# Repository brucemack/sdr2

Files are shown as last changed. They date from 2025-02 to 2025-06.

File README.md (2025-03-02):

Overview
========

This is a homebrew SDR rig with no dependency on external computers/soundcards/etc. 

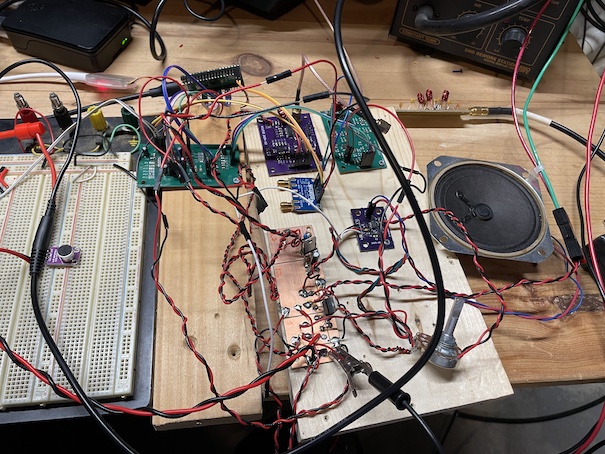
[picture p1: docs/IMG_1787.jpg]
System Picture


Build/Debug Commands
====================

One-time setup of make process:

        git submodule update --init
        mkdir build
        cd build
        cmake -DPICO_BOARD=pico2 ..

Command used to flash code to board:        

        ~/git/openocd/src/openocd -s ~/git/openocd/tcl -f interface/cmsis-dap.cfg -f target/rp2350.cfg -c "adapter speed 5000" -c "rp2350.dap.core1 cortex_m reset_config sysresetreq" -c "program main.elf verify reset exit"

Pico 2 Pinout Notes
===================
```
GP0  - (Reserved for UART0 TX)
GP1  - (Reserved for UART0 RX)

GP2  - 
GP3  - 
GP4  - I2S SCK out to PCM1804 ADC and PCM5100 DAC
GP5  - RST out to PCM1804 ADC

GP6  - I2S DIN in from PC1804 ADC
GP7  - I2S BCK out to PC1804 ADC
GP8  - I2S LRCK out to PC1804 ADC
GP9  - I2S DOUT out to PCM5100 DAC

GP10 - I2S BCK out to PCM5100 DAC
GP11 - I2S LRCK out to PCM5100 DAC
GP12 - User button input 0
GP13 - User button input 1
GP14 - PTT input 
GP15 - 
GP16 - I2C0 SDA for Si5351 (Addr 0x60)
GP17 - I2C0 SCL for Si5351 (Addr 0x60)

GP18 - I2C1 SDA for display and IO expander
GP19 - I2C1 SCL for display and IO expander
GP20 - Rotary encoder I channel input
GP21 - Rotary encoder Q channel input

GP22 - 
GP26 - ADC0 for forward power
GP27 - ADC1 for reverse power
GP28 - 
```
IO Expander Notes
=================
```
P0 - User indicator LED output
P1 - Audio amplifier enable (Low=enable output, high=shutdown amplifier)
P2 - ADC Input Select (Low=Microphone preamp out, High=QSD channel out)
P3 - TX band select 0
P4 - TX band select 1
P5 - RX band select 0
P6 - RX band select 1
P7 - Transmit PA enable (active low)
```

Wiring Notes
============

* TXRX board I_PLUS (J4:1) -> Audio Breakout INL_PLUS (J4:1)
* TXRX board I_MINUS (J4:2) -> Audio Breakout INL_MINUS (J4:2)
* TXRX board Q_PLUS (J4:3) -> Audio Breakout INR_PLUS (J4:4)
* TXRX board Q_MINUS (J4:5) -> Audio Breakout INR_MINUS (J4:3)
* Microphone input is connected to the INL_PLUS/INL_MINUS pins on the audio breakout board.

Hardware Notes
==============

### Instrumentation Amplifiers on Receive Board

See Horowitz and Hill (3rd ed, section 5.16, figure 5.88) for a description of the 
instrumentation amplifier configuration used on the receive board.  Gain for this amplifier is 
controlled determined by 1 + 2 R<sub>f</sub> / R<sub>g</sub>.  Notice that the feedback 
path is tapped after a 47 ohm resistor to set the output impedance of the stage.

Assuming R<sub>f</sub> is 520, R<sub>g</sub> is 100, the theoretical gain is about 11.

### Random

dBm = 30 + 20 * log(Vrms/sqrt(Z0))

Research
========

Consider the PCM1863 ADC? 

Consider the TS5A4624 analog switch (logic high = 2.4V w/ 5V supply)

Consider PCF8574A IO expander: https://www.ti.com/lit/ds/symlink/pcf8574a.pdf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

RF Transistor: https://www.nxp.com/docs/en/data-sheet/BFU590G.pdf

References
==========

[PCM1804 Datasheet](https://www.ti.com/lit/ds/symlink/pcm1804.pdf)
[PCM5100 Datasheet](https://www.ti.com/lit/ds/symlink/pcm5102.pdf)

Steps to Build CMSIS-DSP
========================

The library gets built once in a parallel project:

        cd ~/pico
        mkdir CMSISDSP
        cd CMSISDSP
        git clone https://github.com/ARM-software/CMSIS-DSP.git        
        git clone https://github.com/ARM-software/CMSIS_6.git
        cp $PICO_SDK_PATH/external/pico_sdk_import.cmake .

Then setup the CMakeLists.txt shown below and build:

        mkdir build
        cd build
        # IMPORTANT! pico2 build enables the generation of FPU instructions
        cmake -DPICO_BOARD=pico2 ..
        make -j4

What the CMakeLists.txt looks like:

```
cmake_minimum_required (VERSION 3.6)

# Pull in Pico SDK (must be before project)
include(pico_sdk_import.cmake) 

set(HOME $ENV{HOME})
set(CMSISDSP ${HOME}/pico/CMSISDSP/CMSIS-DSP)
set(CMSISCORE ${HOME}/pico/CMSISDSP/CMSIS_6/CMSIS/Core)

# Define the project
project (cmsis-dsp VERSION 0.1)

# Initialise the Pico SDK
pico_sdk_init()

add_subdirectory(${CMSISDSP}/Source bin_dsp)

target_compile_options(CMSISDSP PUBLIC 
    -Wsign-compare
    -Wdouble-promotion
    -Ofast -ffast-math
    -DNDEBUG
    -Wall -Wextra  -Werror
    -fshort-enums 
    #-fshort-wchar
)
```

Example of referencing the built CMSIS-DSP library in a client project:

```
set(HOME $ENV{HOME})
target_include_directories(main PRIVATE
  ${HOME}/pico/CMSISDSP/CMSIS-DSP/Include
  ${HOME}/pico/CMSISDSP/CMSIS_6/CMSIS/Core/Include
)
target_link_libraries(main
  pico_stdlib
  ${HOME}/pico/CMSISDSP/build/bin_dsp/libCMSISDSP.a
)
```
License
=======

SDR2 Rig - Copyright (C) Bruce MacKinnon KC1FSZ, 2025

This program is free software: you can redistribute it and/or modify
it under the terms of the GNU General Public License as published by
the Free Software Foundation, either version 3 of the License, or
(at your option) any later version.

This program is distributed in the hope that it will be useful,
but WITHOUT ANY WARRANTY; without even the implied warranty of
MERCHANTABILITY or FITNESS FOR A PARTICULAR PURPOSE.  See the
GNU General Public License for more details.

You should have received a copy of the GNU General Public License
along with this program.  If not, see <https://www.gnu.org/licenses/>.

FOR AMATEUR RADIO USE ONLY.
NOT FOR COMMERCIAL USE WITHOUT PERMISSION.

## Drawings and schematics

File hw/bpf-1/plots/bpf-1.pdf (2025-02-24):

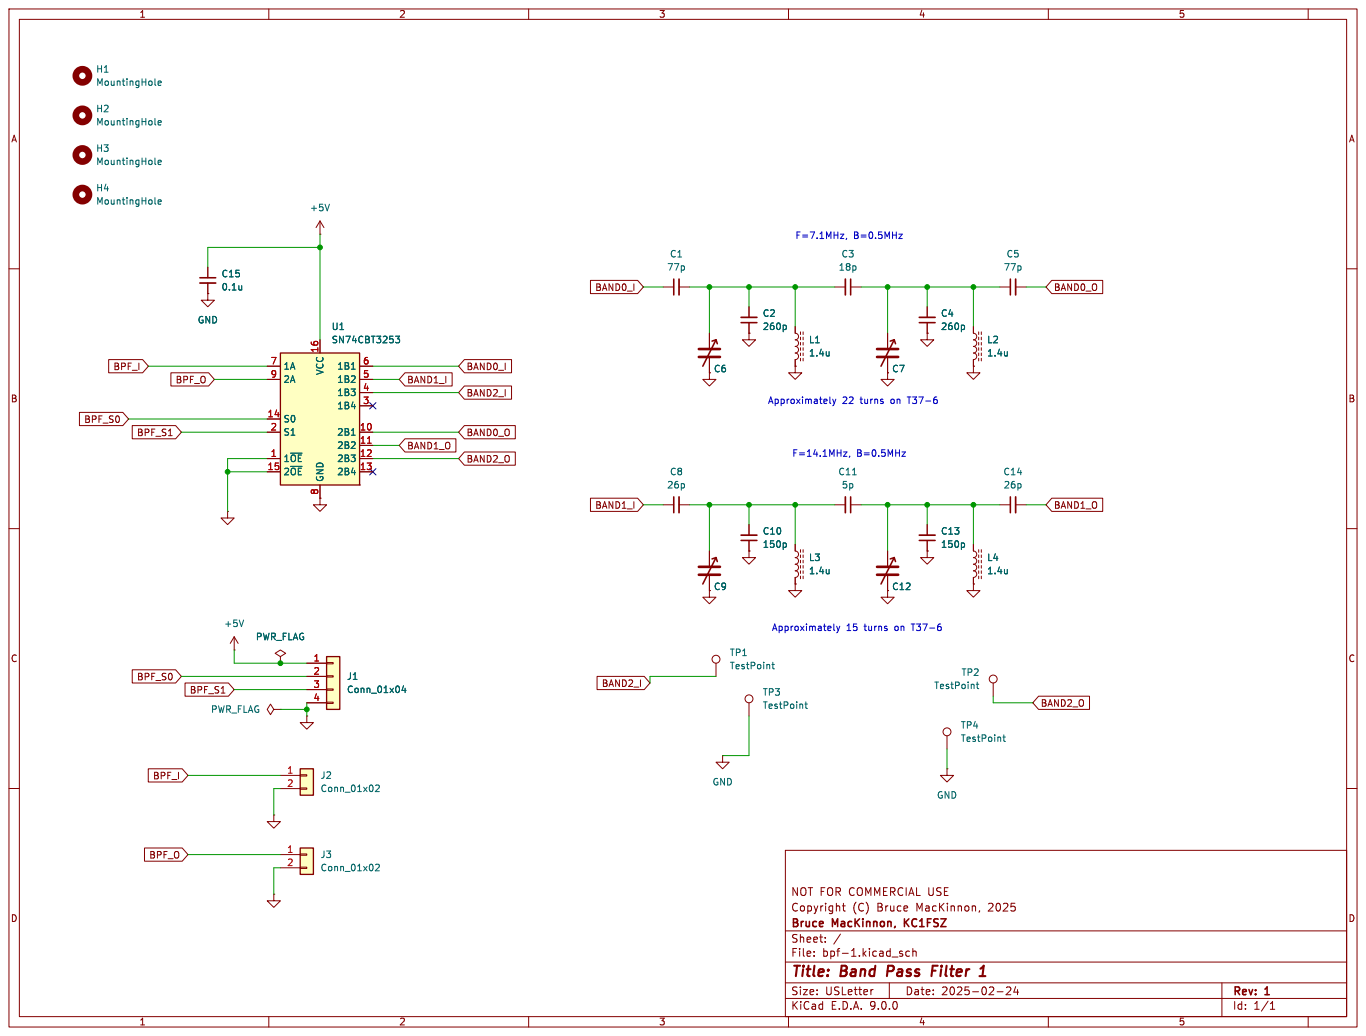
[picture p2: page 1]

Id: 1/1 Title: Band Pass Filter 1

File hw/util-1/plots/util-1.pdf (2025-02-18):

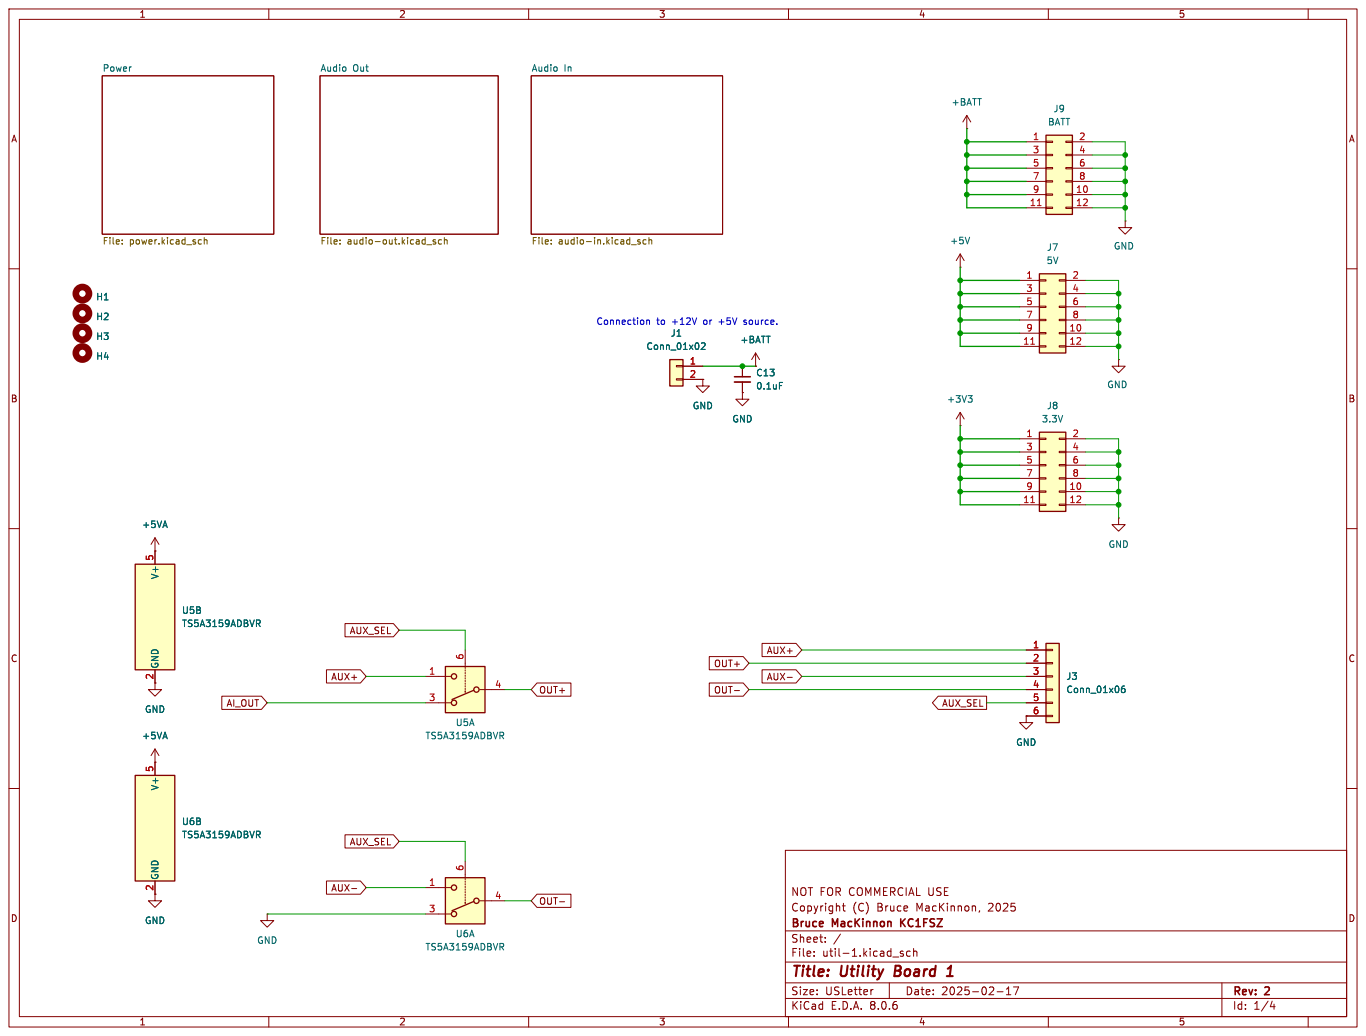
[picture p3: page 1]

9 | 10
11 | 12

Id: 1/4 Title: Utility Board 1

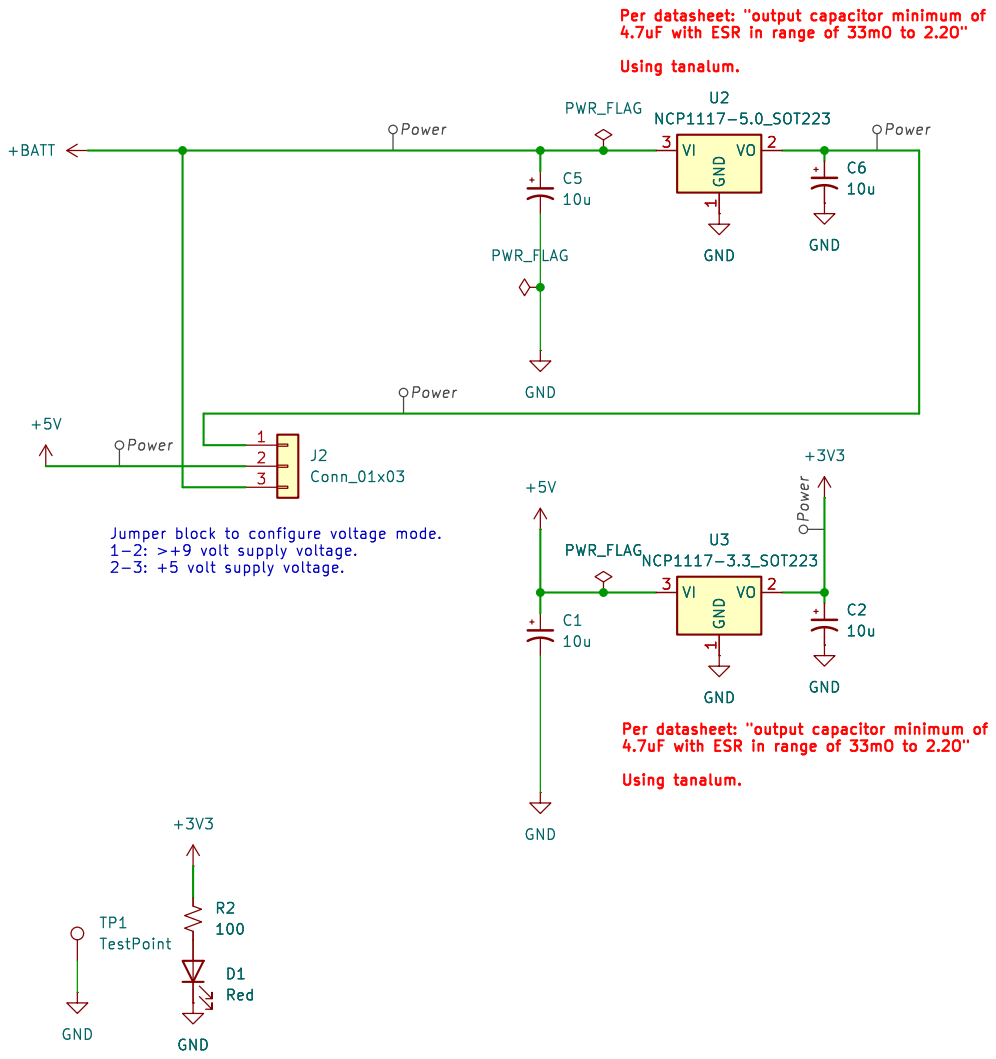
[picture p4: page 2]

1 VO 2 VI 3 D1 Red GND

Id: 2/4 Title: Utility Board 1

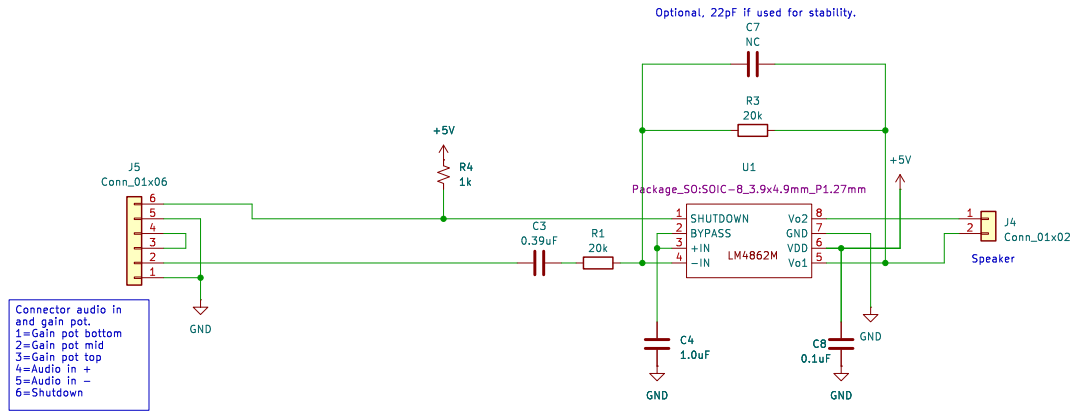
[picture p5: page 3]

and gain pot. 1=Gain pot bottom

Id: 3/4 Title: Utility Board 1

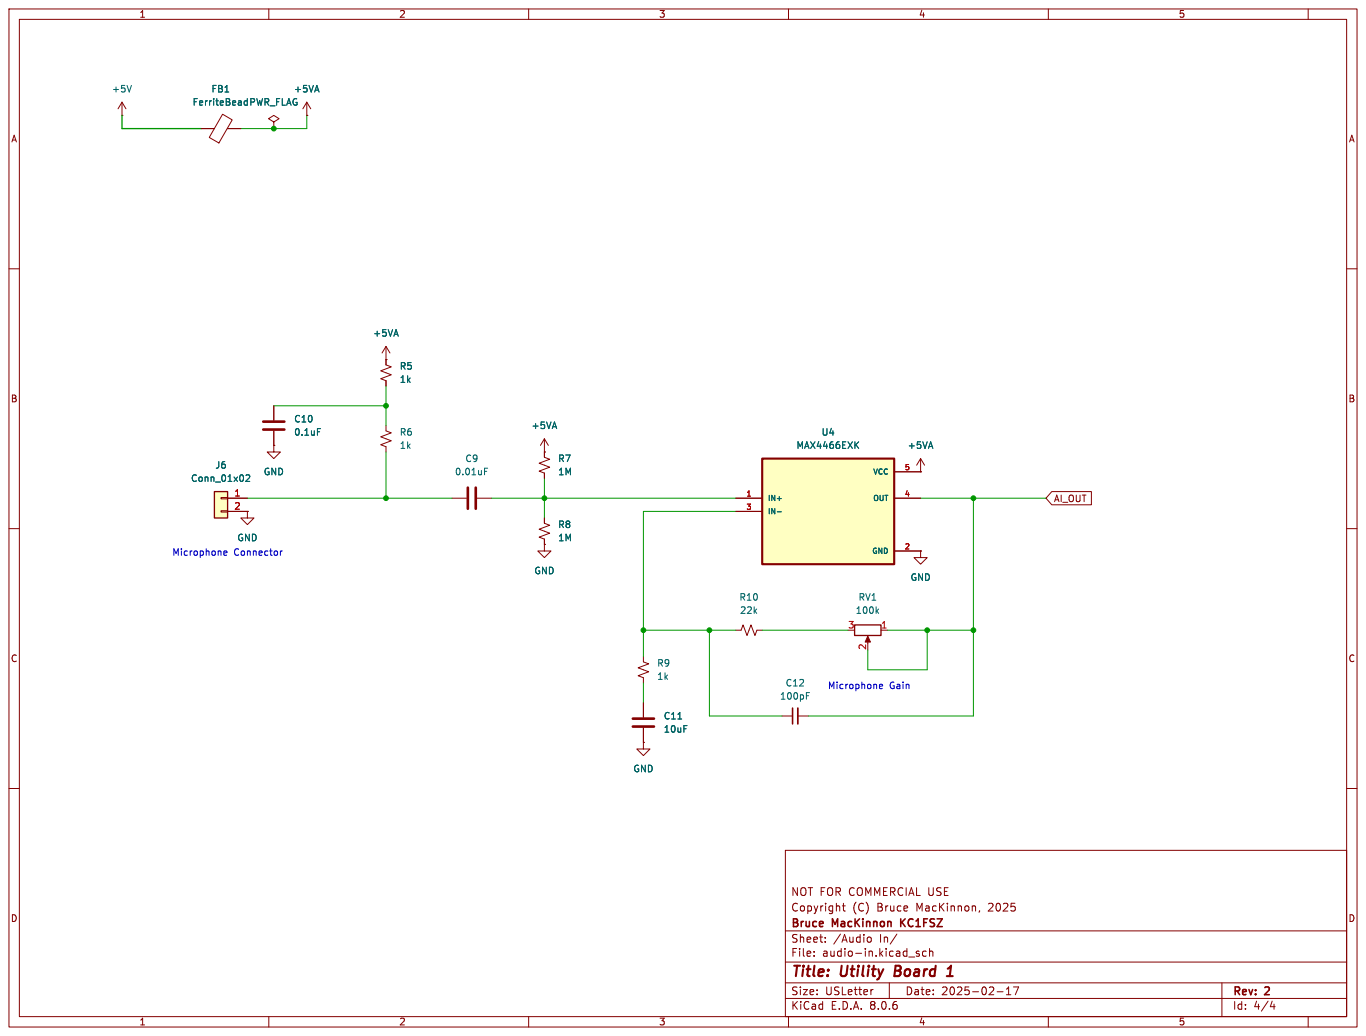
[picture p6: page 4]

Id: 4/4 Title: Utility Board 1

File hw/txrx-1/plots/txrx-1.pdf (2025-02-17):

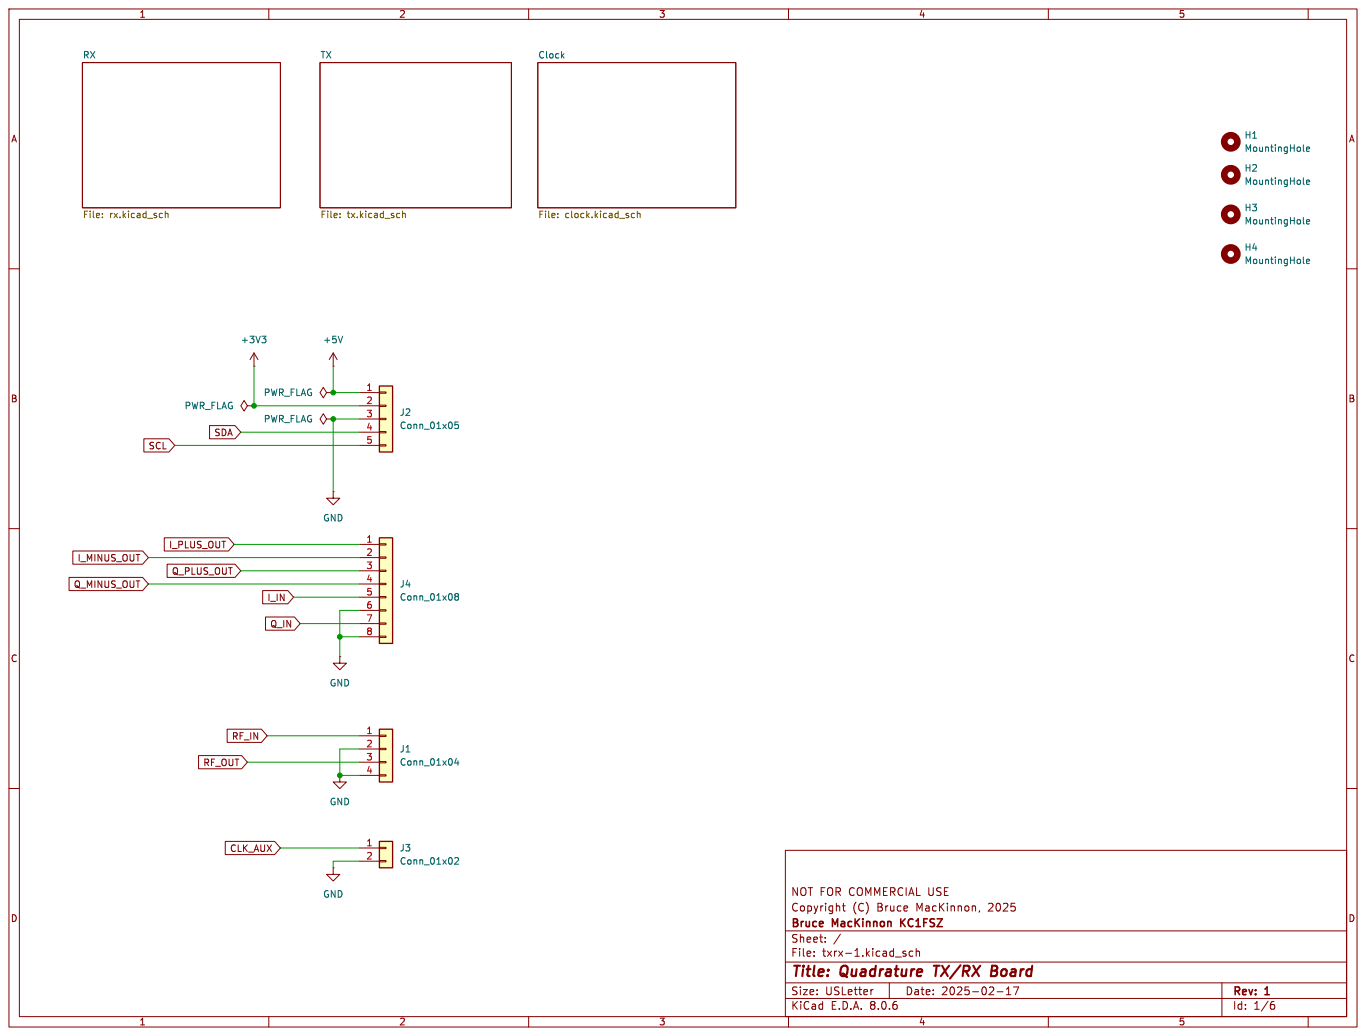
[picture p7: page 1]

Id: 1/6 Title: Quadrature TX/RX Board

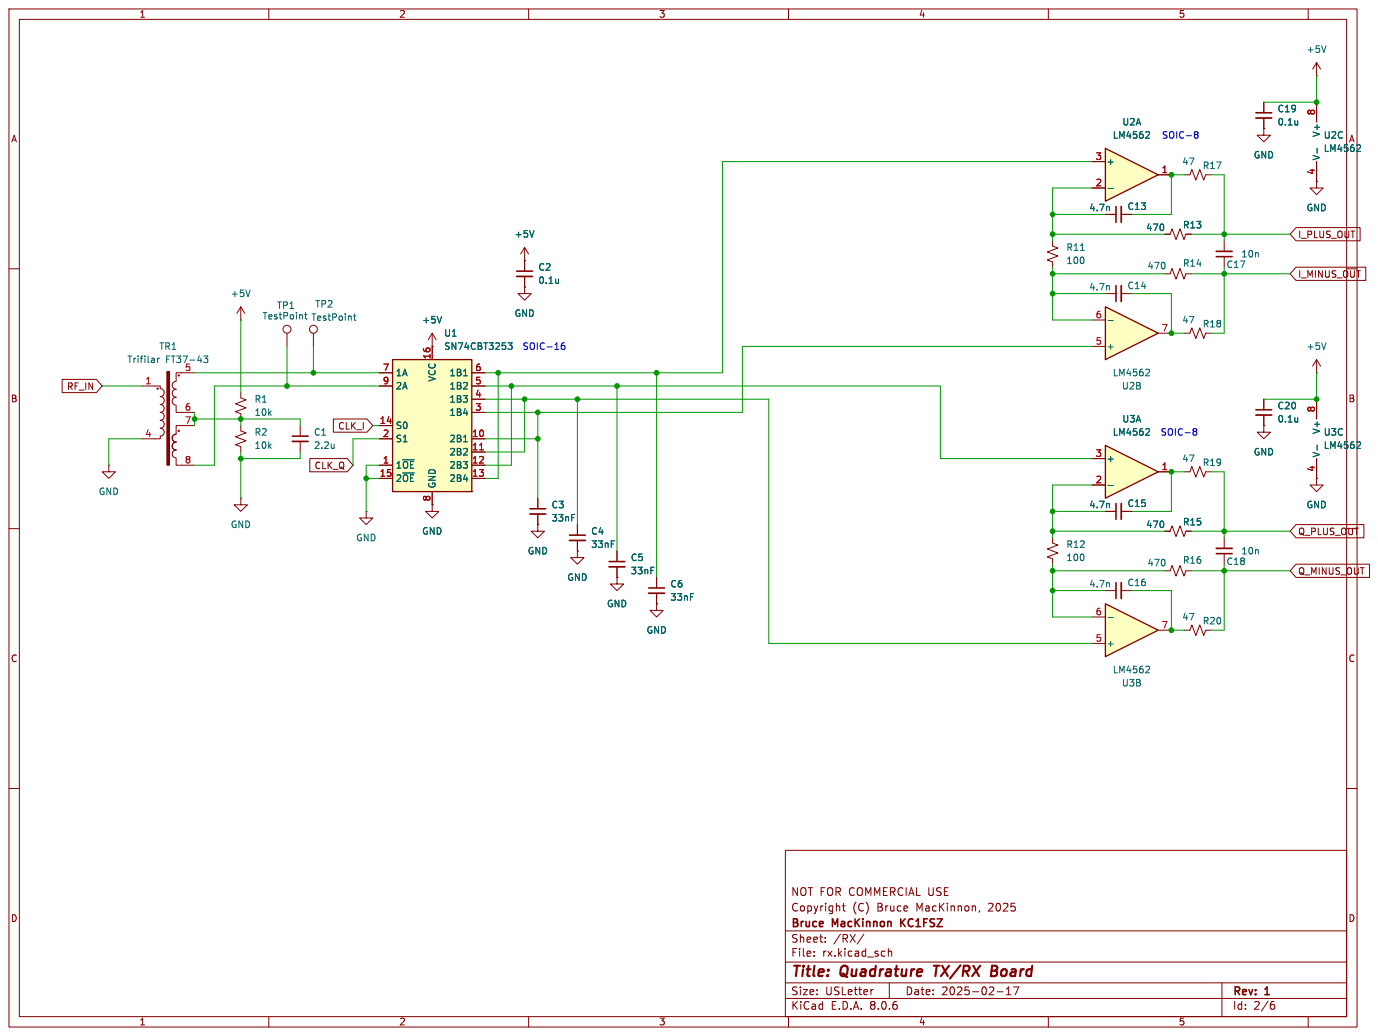
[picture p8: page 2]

Id: 2/6 Title: Quadrature TX/RX Board

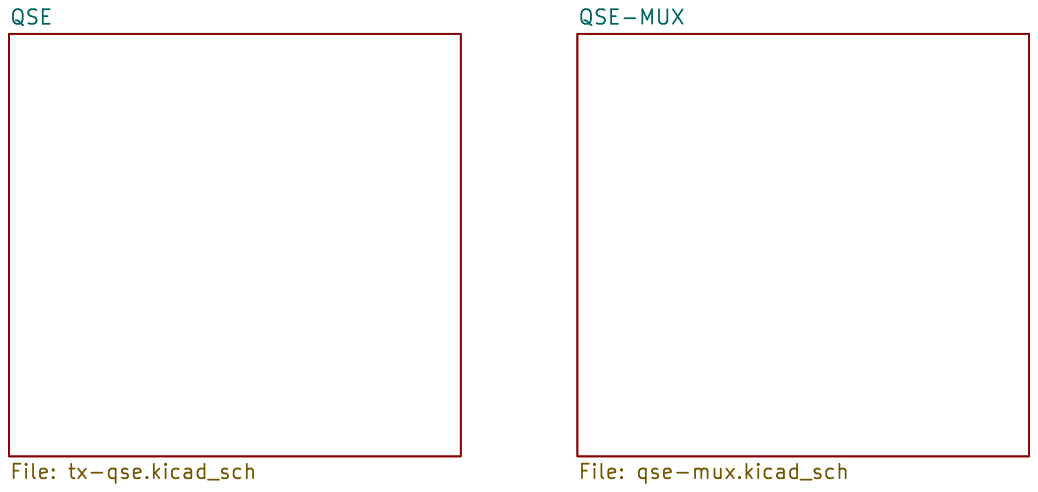
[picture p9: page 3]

File: qse-mux.kicad_sch QSE

Id: 3/6 Title: Quadrature TX/RX Board

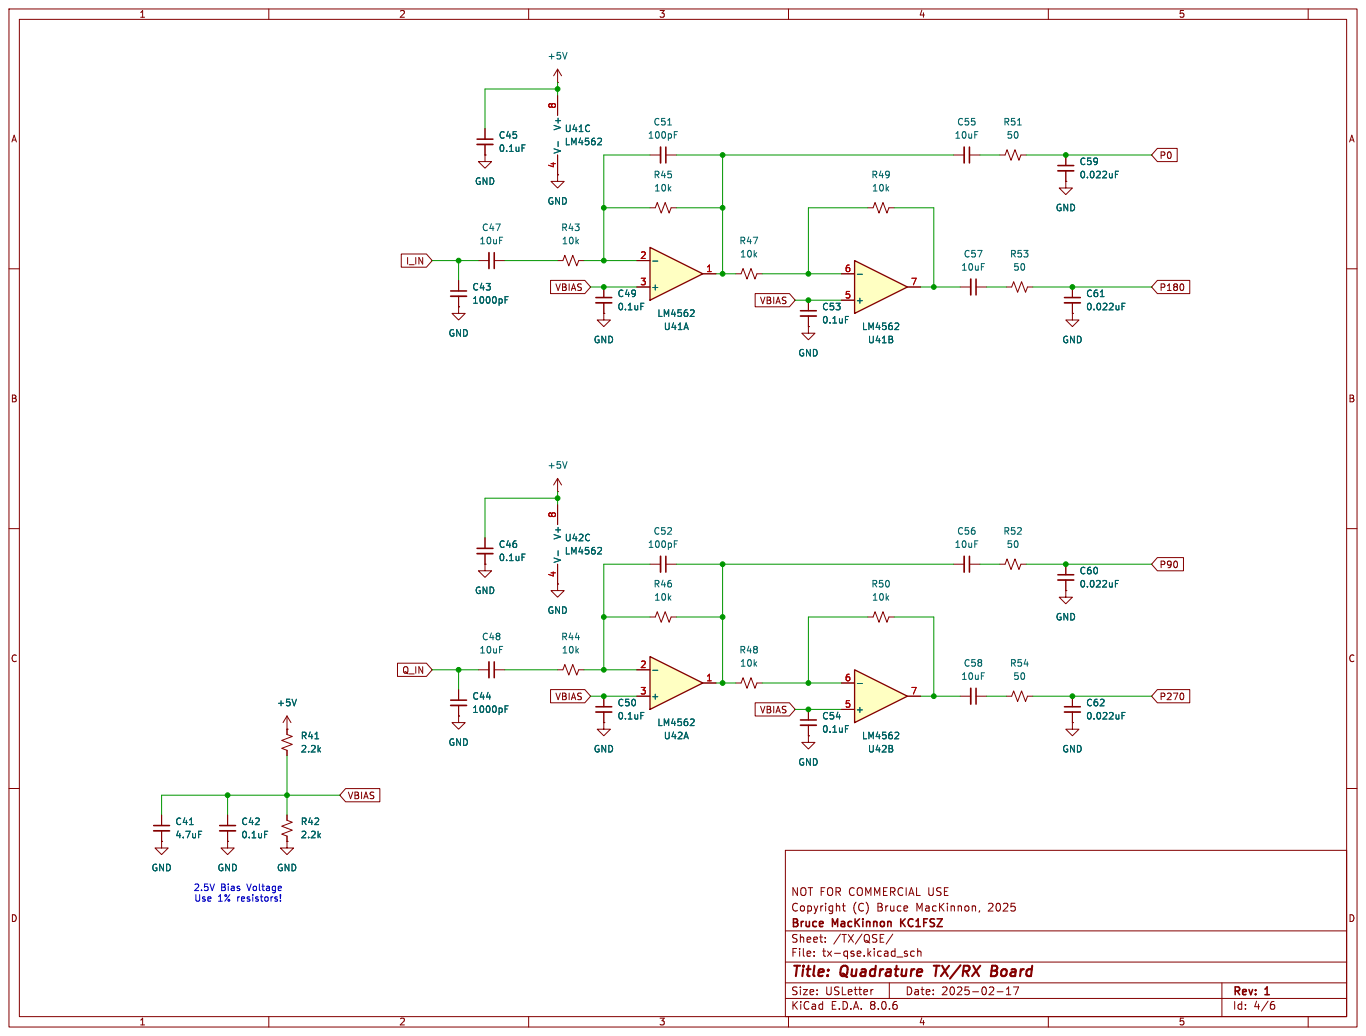
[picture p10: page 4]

Id: 4/6 Title: Quadrature TX/RX Board

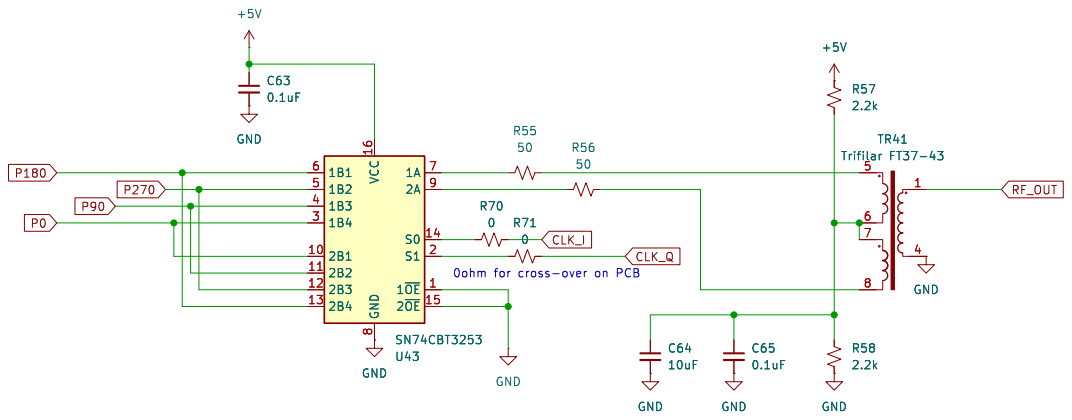
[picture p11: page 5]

Id: 5/6 Title: Quadrature TX/RX Board

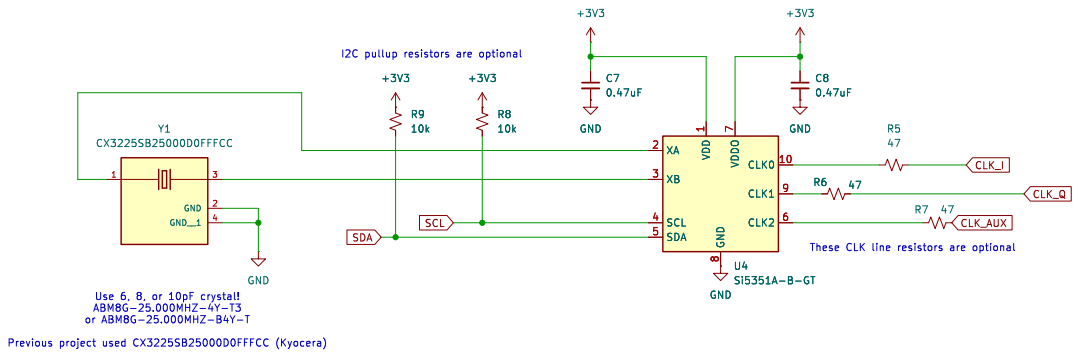
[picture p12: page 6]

1 CLK0 10 XA 2 XB 3 SCL 4 SDA 5 CLK2 6 VDDO

Id: 6/6 Title: Quadrature TX/RX Board

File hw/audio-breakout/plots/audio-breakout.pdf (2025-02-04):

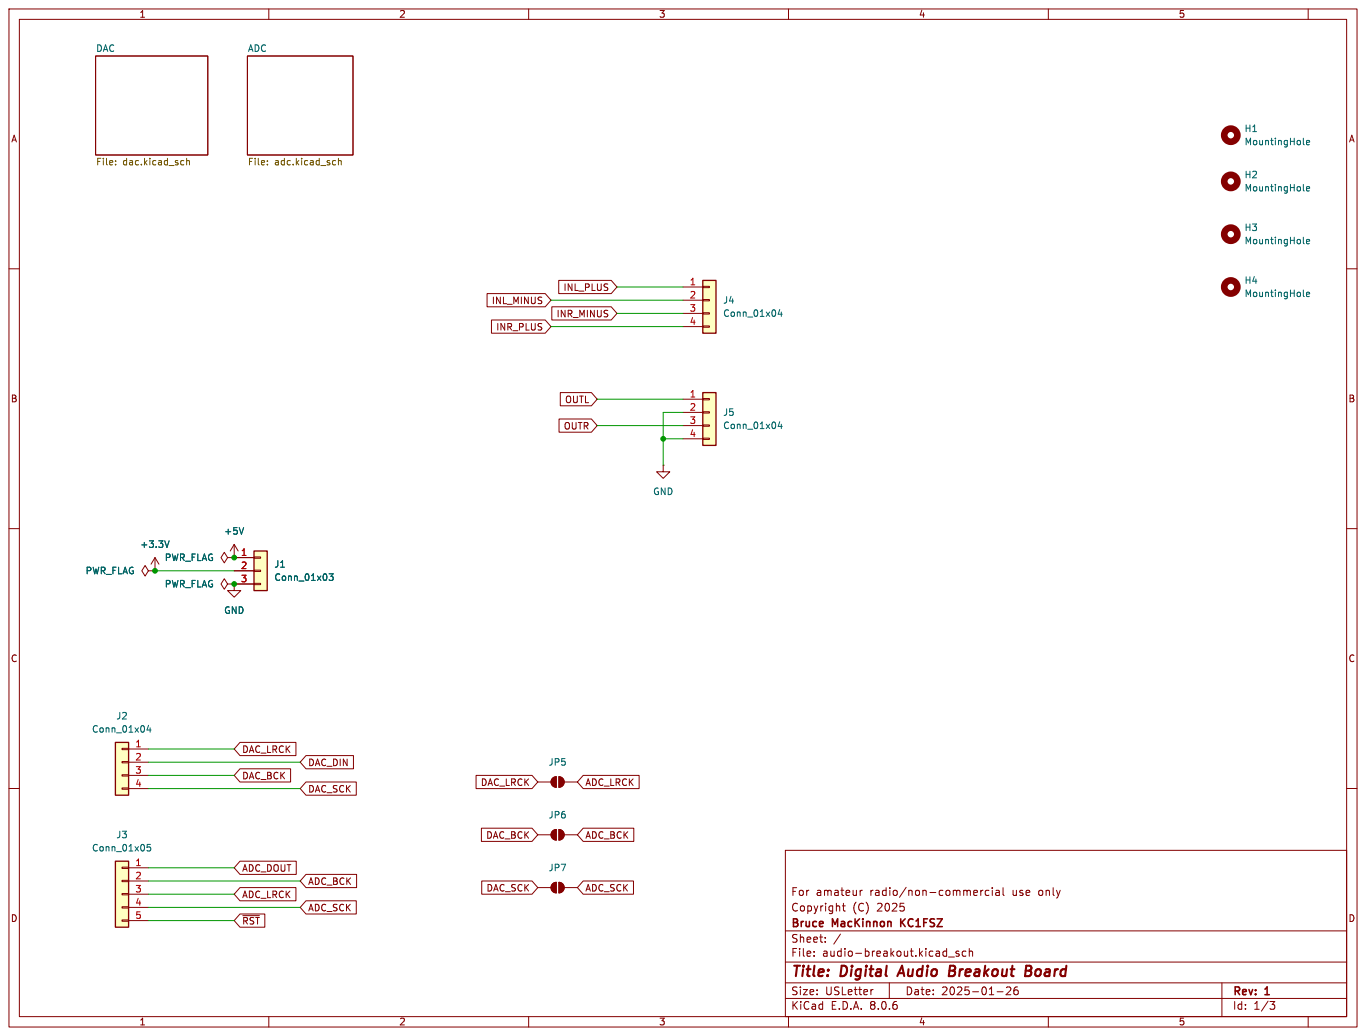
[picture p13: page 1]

Id: 1/3 Title: Digital Audio Breakout Board


For DVDD For CPVDD

1 DEMP 10 FLT 11 SCK 12 BCK 13 DIN 14

3 CAPM 4 VNEG 5 OUTL 6 OUTR 7 AVDD

Id: 2/3 Title: Digital Audio Breakout Board


Id: 3/3 Title: Digital Audio Breakout Board

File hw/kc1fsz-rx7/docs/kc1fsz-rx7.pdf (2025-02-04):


Id: 1/1 Title: PCM1804 Breakout Board

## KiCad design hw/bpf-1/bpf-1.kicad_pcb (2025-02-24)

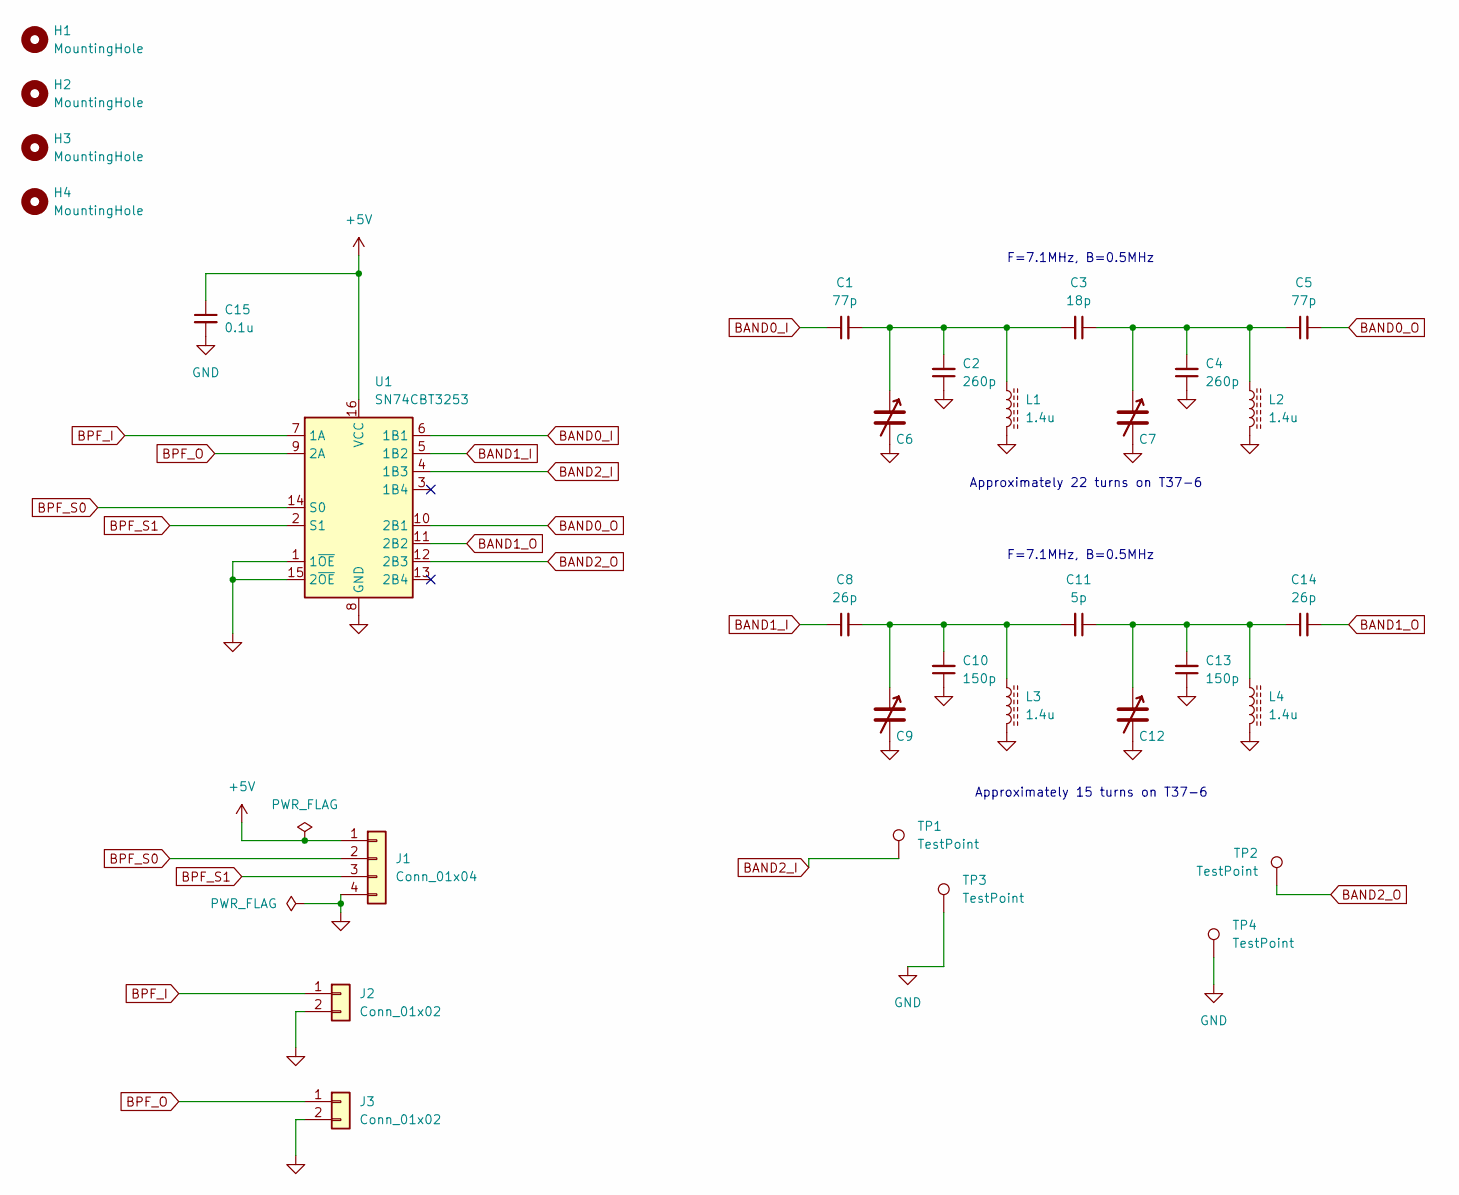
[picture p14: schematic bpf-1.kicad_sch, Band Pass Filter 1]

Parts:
C1, C5: 77p; C_0805_2012Metric_HandSolder
C2, C4: 260p; C_0805_2012Metric_HandSolder
C3: 18p; C_0805_2012Metric_HandSolder
C6, C7, C9, C12: C_Variable; VCAP_GKG30086-05_SGM-L
C8, C14: 26p; C_0805_2012Metric_HandSolder
C10, C13: 150p; C_0805_2012Metric_HandSolder
C11: 5p; C_0805_2012Metric_HandSolder
C15: 0.1u; C_0805_2012Metric_HandSolder
H1, H2, H3, H4: MountingHole; MountingHole_3.5mm
J1: Conn_01x04; PinHeader_1x04_P2.54mm_Vertical
J2, J3: Conn_01x02; PinHeader_1x02_P2.54mm_Vertical
L1, L2, L3, L4: 1.4u; FT37-43 Unifilar
TP1, TP2, TP3, TP4: TestPoint; TestPoint_Pad_1.5x1.5mm
U1: SN74CBT3253; SOIC-16_3.9x9.9mm_P1.27mm

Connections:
+5V: C15.1, J1.1, U1.16 (VCC)
BAND0_I: C1.1, U1.6 (1B1)
BAND0_O: C5.2, U1.10 (2B1)
BAND1_I: C8.1, U1.5 (1B2)
BAND1_O: C14.2, U1.11 (2B2)
BAND2_I: TP1.1, U1.4 (1B3)
BAND2_O: TP2.1, U1.12 (2B3)
BPF_I: J2.1, U1.7 (1A)
BPF_O: J3.1, U1.9 (2A)
BPF_S0: J1.2, U1.14 (S0)
BPF_S1: J1.3, U1.2 (S1)
GND: C2.1, C4.1, C6.2, C7.2, C9.2, C10.1, C12.2, C13.1, C15.2, J1.4, J2.2, J3.2, L1.2, L2.2, L3.2, L4.2, TP3.1, TP4.1, U1.1 (1~OE), U1.8 (GND), U1.15 (2~OE)
unnamed: C1.2, C2.2, C3.2, C6.1, L1.1
unnamed: C3.1, C4.2, C5.1, C7.1, L2.1
unnamed: C8.2, C9.1, C10.2, C11.2, L3.1
unnamed: C11.1, C12.1, C13.2, C14.1, L4.1

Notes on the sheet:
F=7.1MHz, B=0.5MHz
Approximately 15 turns on T37-6
Approximately 22 turns on T37-6

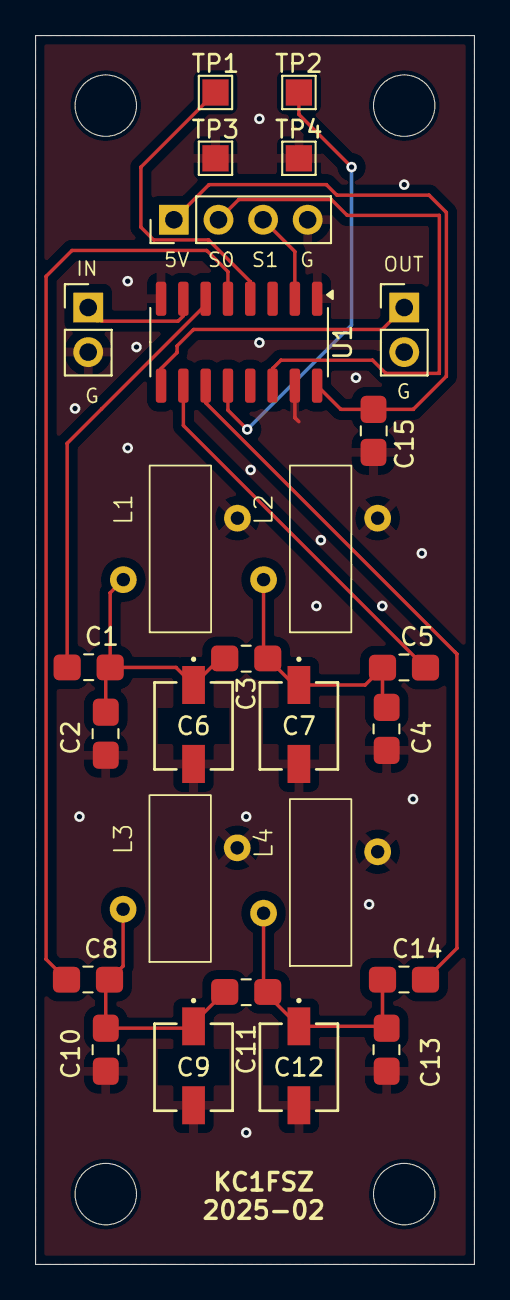
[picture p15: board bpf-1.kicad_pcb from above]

Board: 2 copper layers, 25.0 x 70.0 mm, 31 parts (0 on the bottom side), 16 nets.

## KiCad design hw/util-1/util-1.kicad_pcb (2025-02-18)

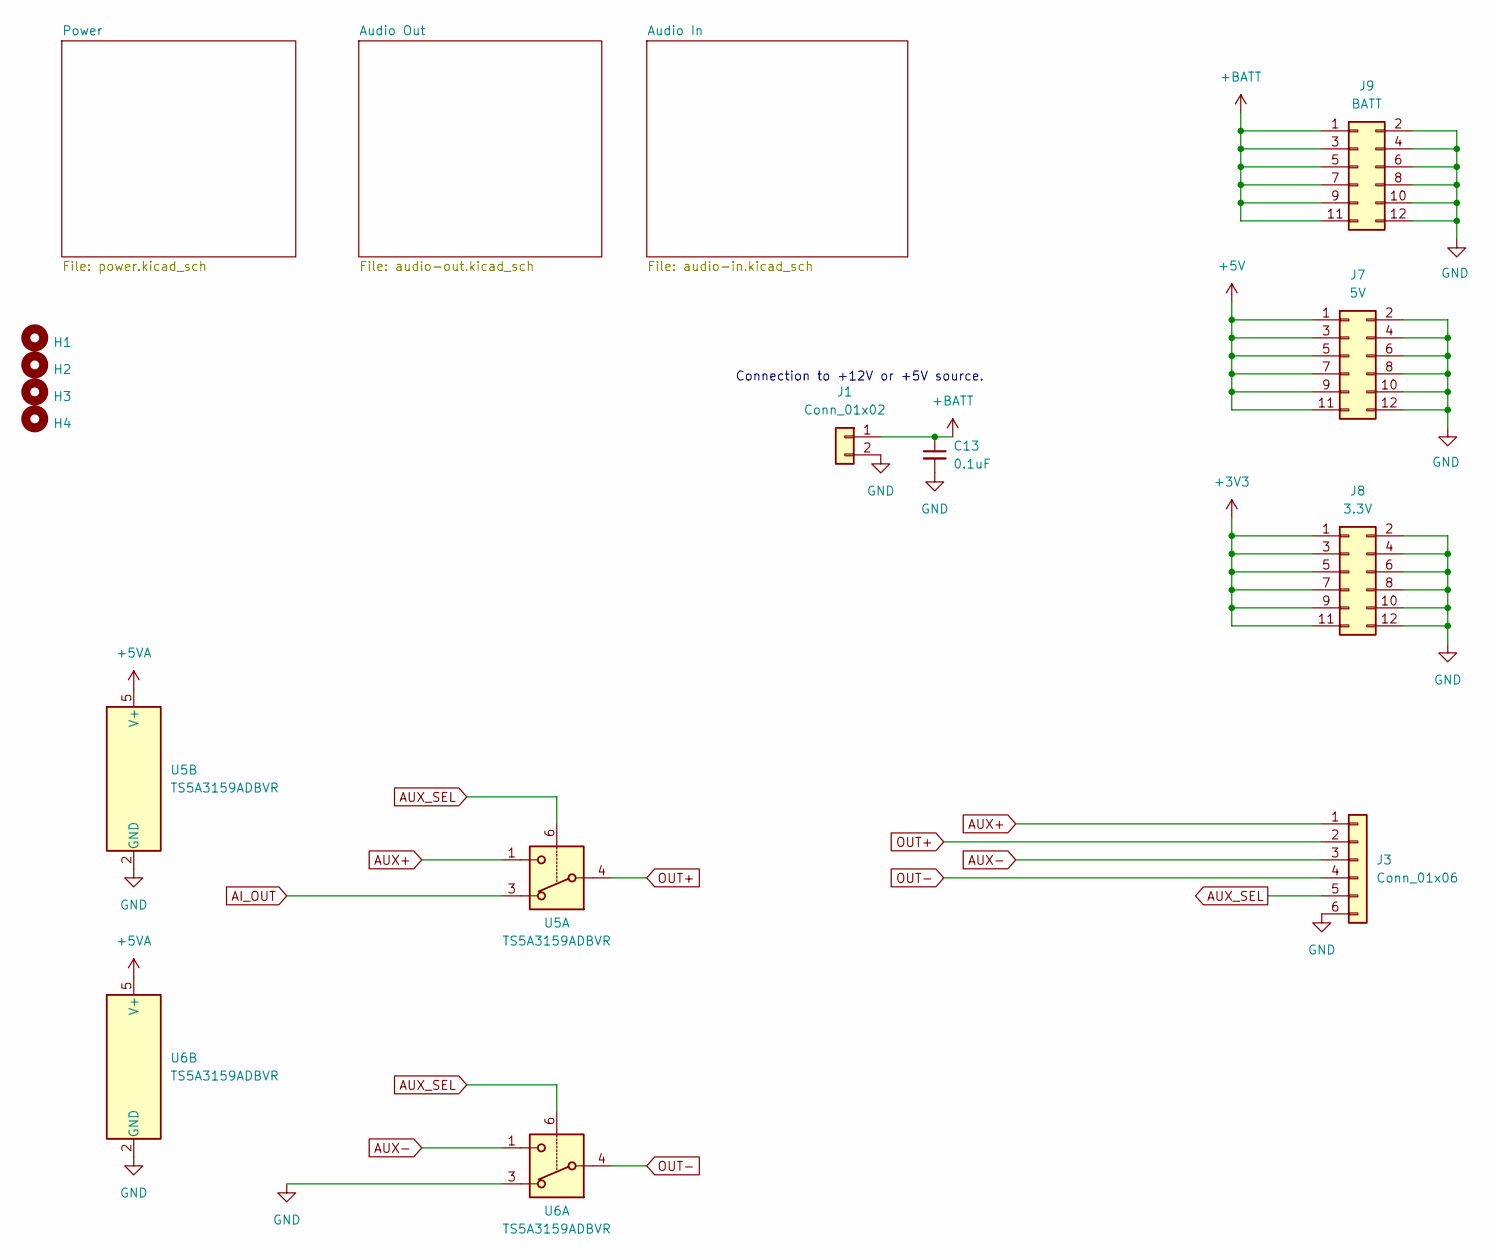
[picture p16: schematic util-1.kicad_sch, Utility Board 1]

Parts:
C13: 0.1uF; C_0805_2012Metric_Pad1.18x1.45mm_HandSolder
H1, H2, H3, H4: MountingHole; MountingHole_4mm
J1: Conn_01x02; PinHeader_1x02_P2.54mm_Vertical
J3: Conn_01x06; PinHeader_1x06_P2.54mm_Vertical
J7: 5V; PinHeader_2x06_P2.54mm_Vertical
J8: 3.3V; PinHeader_2x06_P2.54mm_Vertical
J9: BATT; PinHeader_2x06_P2.54mm_Vertical
U5, U6: TS5A3159ADBVR; SOT-23-6

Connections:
+3V3: J8.1, J8.3, J8.5, J8.7, J8.9, J8.11; also elsewhere on the board
+5V: J7.1, J7.3, J7.5, J7.7, J7.9, J7.11; also elsewhere on the board
+5VA: U5.5 (V+), U6.5 (V+); also elsewhere on the board
+BATT: C13.1, J1.1, J9.1, J9.3, J9.5, J9.7, J9.9, J9.11; also elsewhere on the board
AI_OUT: U5.3; also elsewhere on the board
AUX+: J3.1, U5.1
AUX-: J3.3, U6.1
AUX_SEL: J3.5, U5.6, U6.6
GND: C13.2, J1.2, J3.6, J7.2, J7.4, J7.6, J7.8, J7.10, J7.12, J8.2, J8.4, J8.6, J8.8, J8.10, J8.12, J9.2, J9.4, J9.6, J9.8, J9.10, J9.12, U5.2 (GND), U6.2 (GND), U6.3; also elsewhere on the board
OUT+: J3.2, U5.4
OUT-: J3.4, U6.4

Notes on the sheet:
Connection to +12V or +5V source.

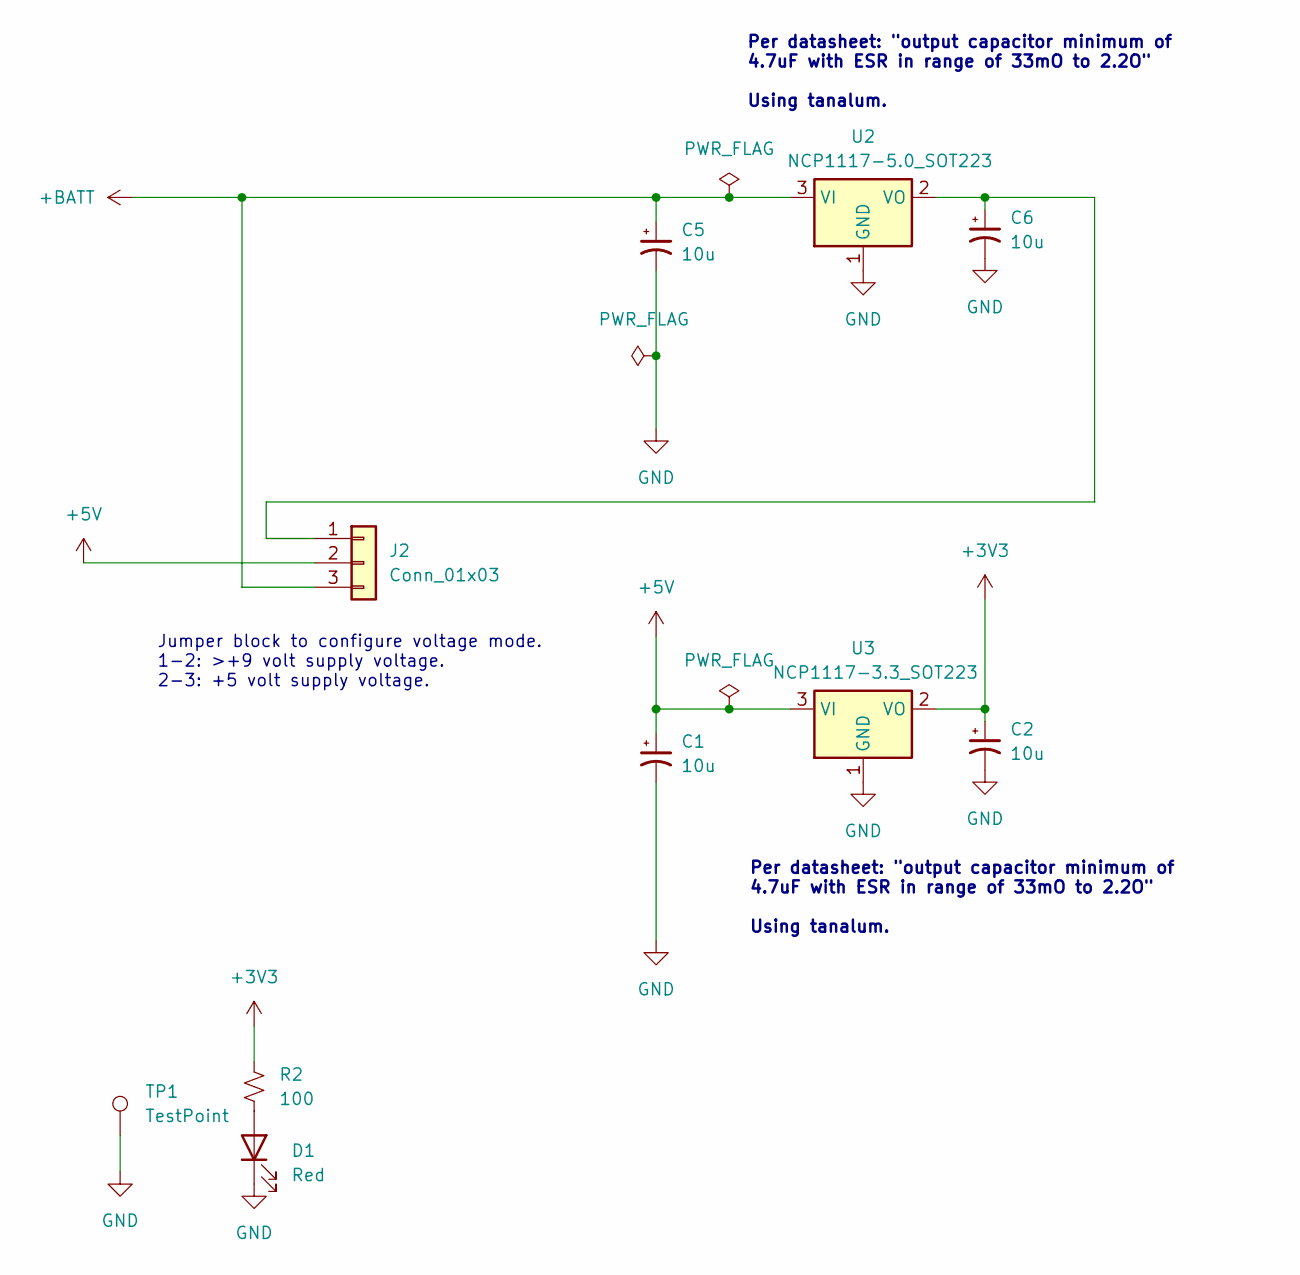
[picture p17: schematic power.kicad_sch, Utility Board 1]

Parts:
C1, C2, C5, C6: 10u; CPOL_0805_2012Metric_Pad1.18x1.45mm_HandSolder
D1: Red; LED_0805_2012Metric_Pad1.15x1.40mm_HandSolder
J2: Conn_01x03; PinHeader_1x03_P2.54mm_Vertical
R2: 100; R_0805_2012Metric_Pad1.20x1.40mm_HandSolder
TP1: TestPoint; TestPoint_Pad_2.5x2.5mm
U2: NCP1117-5.0_SOT223; SOT-223-3_TabPin2
U3: NCP1117-3.3_SOT223; SOT-223-3_TabPin2

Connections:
+3V3: C2.1, R2.1, U3.2 (VO); also elsewhere on the board
+5V: C1.1, J2.2, U3.3 (VI); also elsewhere on the board
+BATT: C5.1, J2.3, U2.3 (VI); also elsewhere on the board
GND: C1.2, C2.2, C5.2, C6.2, D1.1 (K), TP1.1, U2.1 (GND), U3.1 (GND); also elsewhere on the board
unnamed: D1.2 (A), R2.2
unnamed: C6.1, J2.1, U2.2 (VO)

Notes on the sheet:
Per datasheet: "output capacitor minimum of 4.7uF with ESR in range of 33mO to 2.2O" Using tanalum.
Jumper block to configure voltage mode. 1-2: >+9 volt supply voltage. 2-3: +5 volt supply voltage.

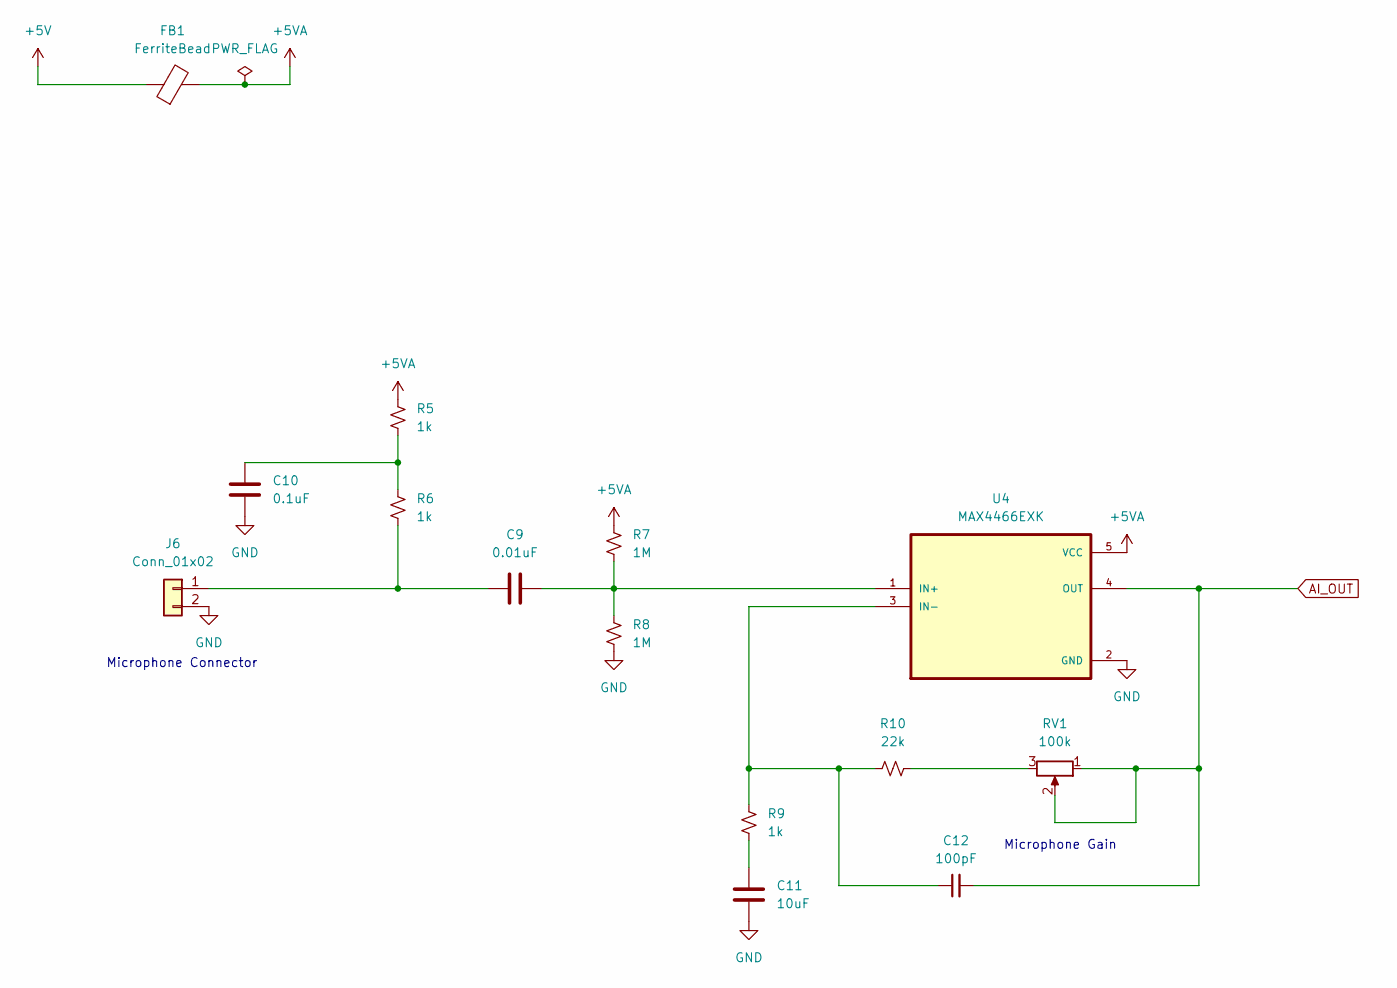
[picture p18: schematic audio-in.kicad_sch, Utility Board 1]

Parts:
C9: 0.01uF; C_0805_2012Metric_Pad1.18x1.45mm_HandSolder
C10: 0.1uF; C_0805_2012Metric_Pad1.18x1.45mm_HandSolder
C11: 10uF; C_0805_2012Metric_Pad1.18x1.45mm_HandSolder
C12: 100pF; C_0805_2012Metric_Pad1.18x1.45mm_HandSolder
FB1: FerriteBead; L_0805_2012Metric_Pad1.15x1.40mm_HandSolder
J6: Conn_01x02; PinHeader_1x02_P2.54mm_Vertical
R5, R6, R9: 1k; R_0805_2012Metric_Pad1.20x1.40mm_HandSolder
R7, R8: 1M; R_0805_2012Metric_Pad1.20x1.40mm_HandSolder
R10: 22k; R_0805_2012Metric_Pad1.20x1.40mm_HandSolder
RV1: 100k; POT_3362P
U4: MAX4466EXK; SOT-353_SC-70-5_Handsoldering

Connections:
+5V: FB1.1; also elsewhere on the board
+5VA: FB1.2, R5.1, R7.1, U4.5 (VCC); also elsewhere on the board
AI_OUT: C12.2, RV1.1, RV1.2, U4.4 (OUT); also elsewhere on the board
GND: C10.1, C11.1, J6.2, R8.2, U4.2 (GND); also elsewhere on the board
unnamed: C10.2, R5.2, R6.1
unnamed: C11.2, R9.2
unnamed: C9.1, J6.1, R6.2
unnamed: R10.2, RV1.3
unnamed: C9.2, R7.2, R8.1, U4.1 (IN+)
unnamed: C12.1, R9.1, R10.1, U4.3 (IN-)

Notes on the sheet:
Microphone Connector
Microphone Gain

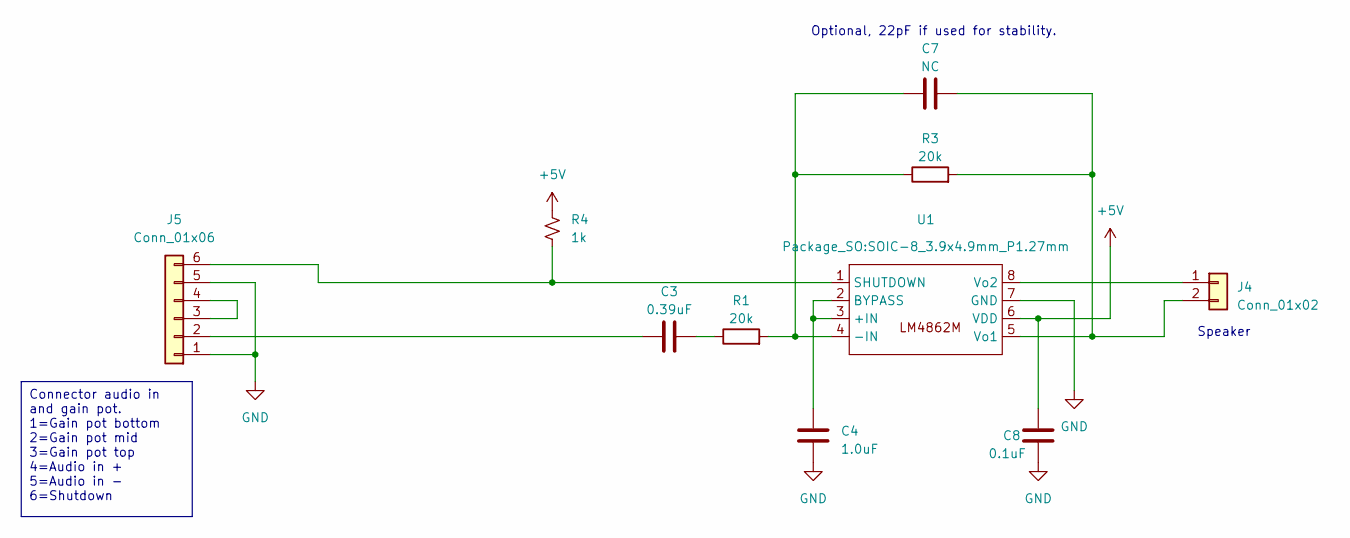
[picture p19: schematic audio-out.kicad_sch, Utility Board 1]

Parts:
C3: 0.39uF; C_0805_2012Metric_Pad1.18x1.45mm_HandSolder
C4: 1.0uF; C_0805_2012Metric_Pad1.18x1.45mm_HandSolder
C7: NC; C_0805_2012Metric_Pad1.18x1.45mm_HandSolder
C8: 0.1uF; C_0805_2012Metric_Pad1.18x1.45mm_HandSolder
J4: Conn_01x02; PinHeader_1x02_P2.54mm_Vertical
J5: Conn_01x06; PinHeader_1x06_P2.54mm_Vertical
R1, R3: 20k; R_0805_2012Metric_Pad1.20x1.40mm_HandSolder
R4: 1k; R_0805_2012Metric_Pad1.20x1.40mm_HandSolder
U1: SOIC-8_3.9x4.9mm_P1.27mm

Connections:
+5V: C8.1, R4.1, U1.6 (VDD); also elsewhere on the board
GND: C4.2, C8.2, J5.1, J5.5, U1.7 (GND); also elsewhere on the board
unnamed: C3.2, R1.1
unnamed: J4.1, U1.8 (Vo2)
unnamed: C7.1, J4.2, R3.2, U1.5 (Vo1)
unnamed: C3.1, J5.2
unnamed: J5.3, J5.4
unnamed: J5.6, R4.2, U1.1 (SHUTDOWN)
unnamed: C4.1, U1.2 (BYPASS), U1.3 (+IN)
unnamed: C7.2, R1.2, R3.1, U1.4 (-IN)

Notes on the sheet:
Connector audio in and gain pot. 1=Gain pot bottom 2=Gain pot mid 3=Gain pot top 4=Audio in + 5=Audio in - 6=Shutdown
Speaker
Optional, 22pF if used for stability.

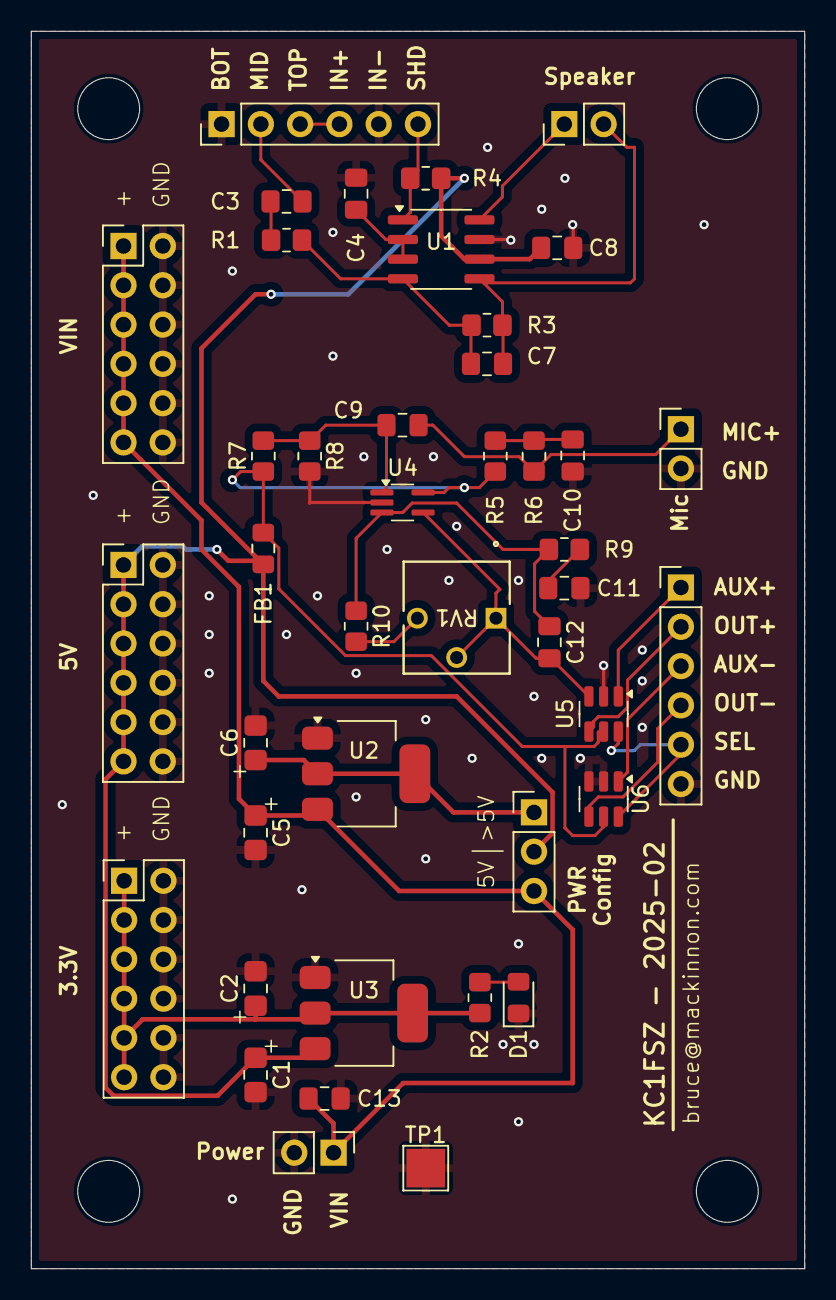
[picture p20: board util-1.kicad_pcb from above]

Board: 2 copper layers, 50.0 x 80.0 mm, 46 parts (0 on the bottom side), 27 nets.

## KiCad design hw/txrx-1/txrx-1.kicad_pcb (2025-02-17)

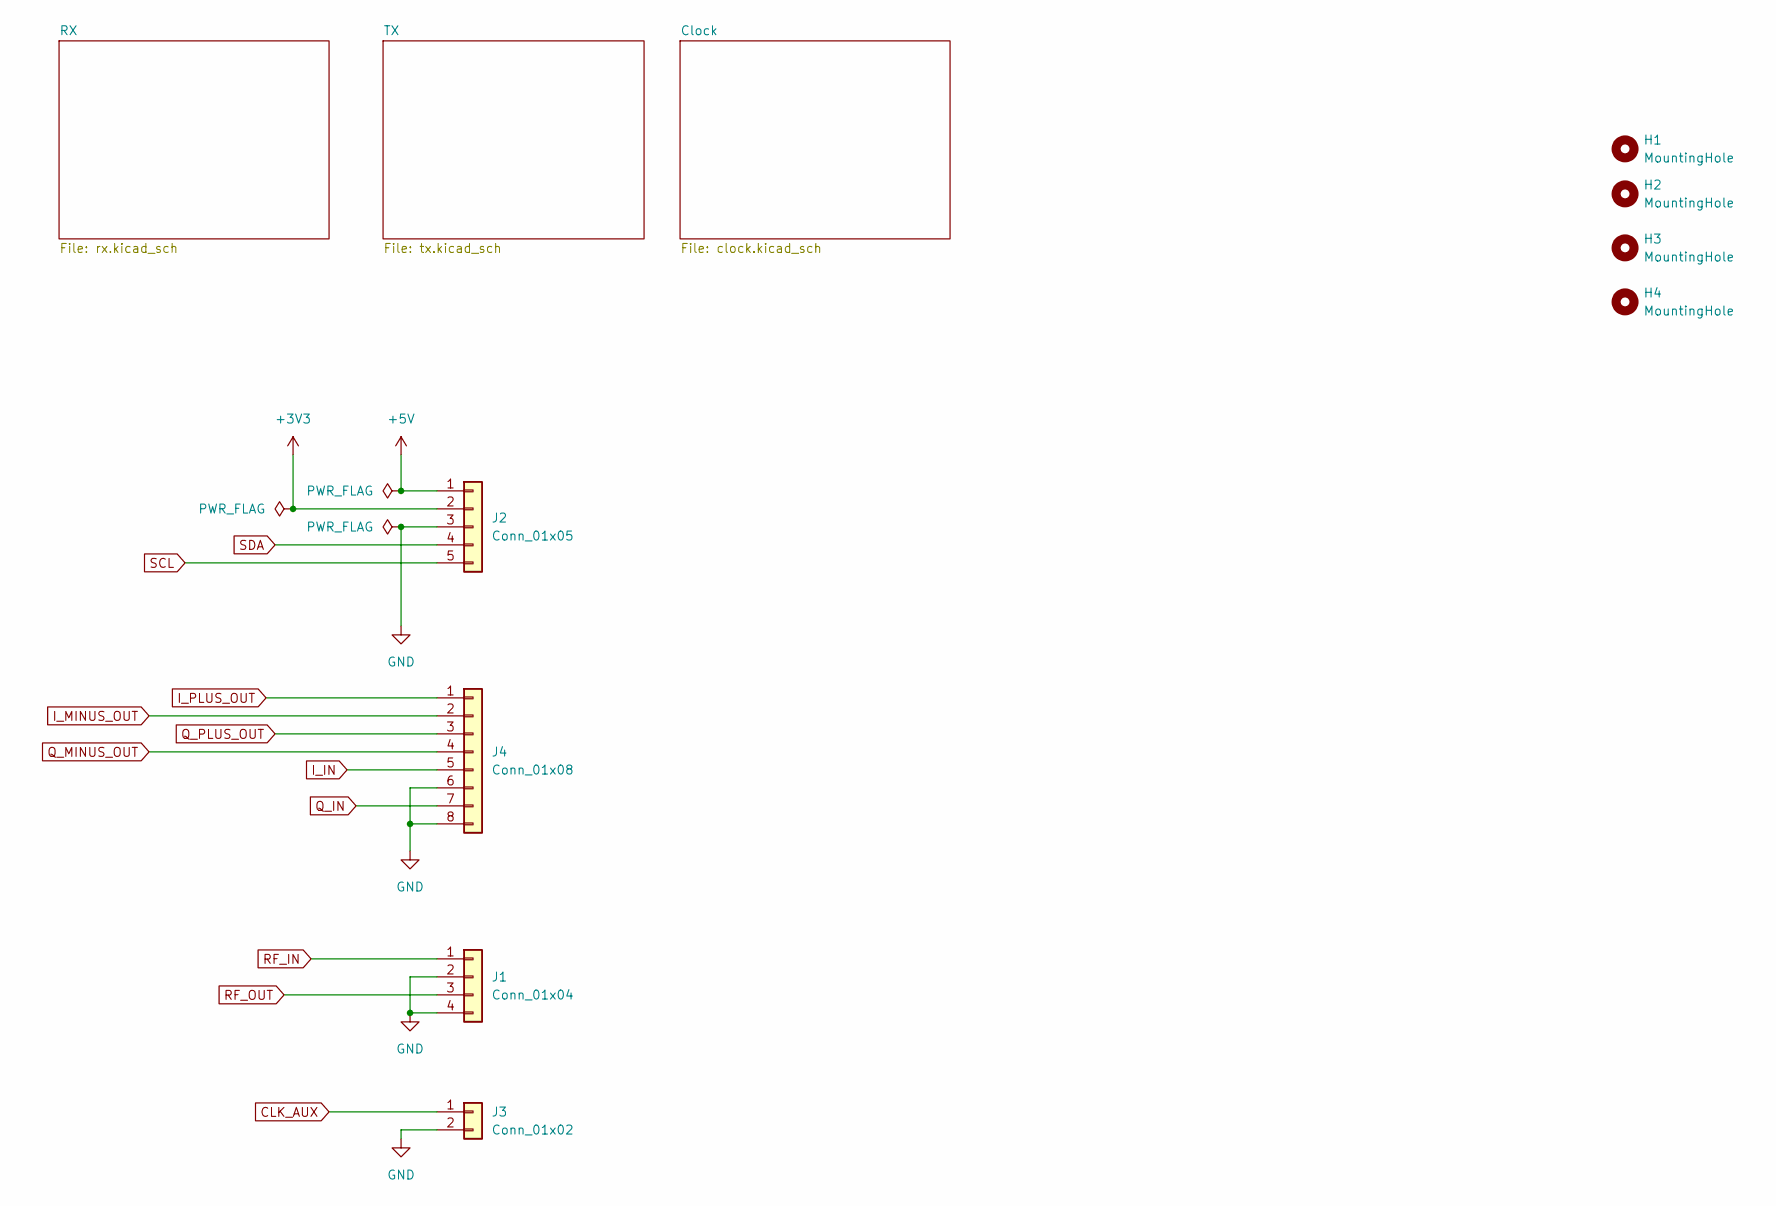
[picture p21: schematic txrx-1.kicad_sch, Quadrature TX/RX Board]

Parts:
H1, H2, H3, H4: MountingHole; MountingHole_3.5mm
J1: Conn_01x04; PinHeader_1x04_P2.54mm_Vertical
J2: Conn_01x05; PinHeader_1x05_P2.54mm_Vertical
J3: Conn_01x02; PinHeader_1x02_P2.54mm_Vertical
J4: Conn_01x08; PinHeader_1x08_P2.54mm_Vertical

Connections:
+3V3: J2.2; also elsewhere on the board
+5V: J2.1; also elsewhere on the board
CLK_AUX: J3.1; also elsewhere on the board
GND: J1.2, J1.4, J2.3, J3.2, J4.6, J4.8; also elsewhere on the board
I_IN: J4.5; also elsewhere on the board
I_MINUS_OUT: J4.2; also elsewhere on the board
I_PLUS_OUT: J4.1; also elsewhere on the board
Q_IN: J4.7; also elsewhere on the board
Q_MINUS_OUT: J4.4; also elsewhere on the board
Q_PLUS_OUT: J4.3; also elsewhere on the board
RF_IN: J1.1; also elsewhere on the board
RF_OUT: J1.3; also elsewhere on the board
SCL: J2.5; also elsewhere on the board
SDA: J2.4; also elsewhere on the board

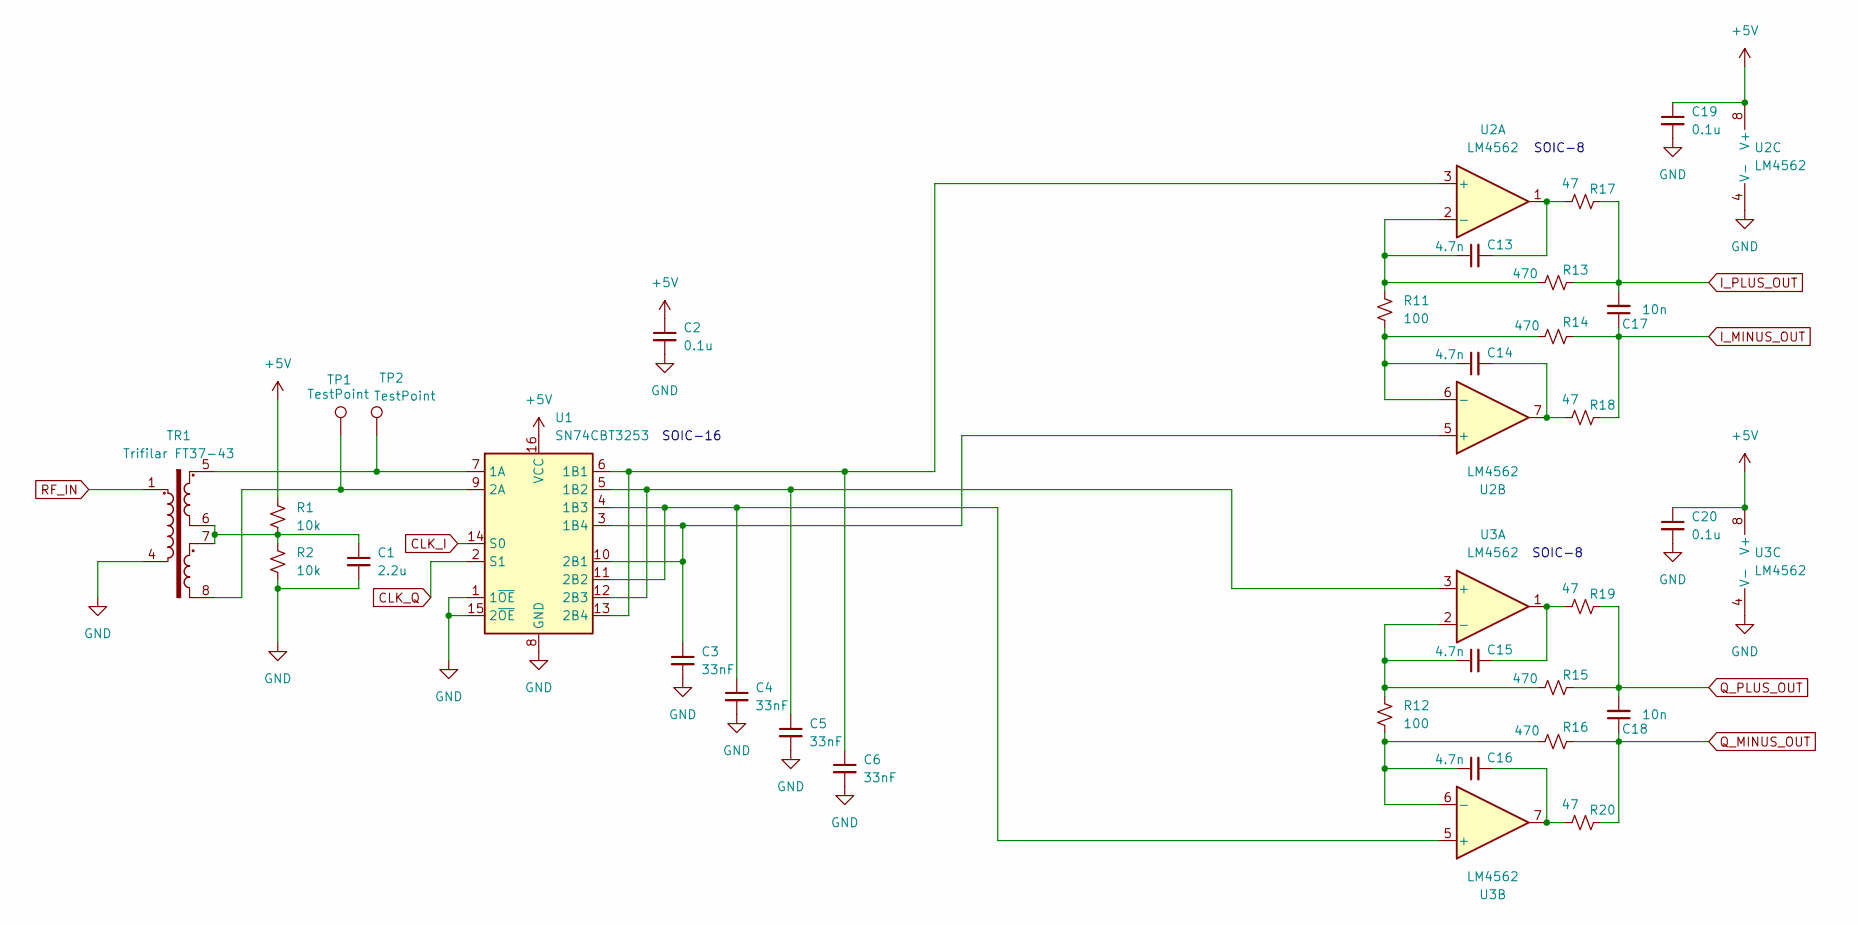
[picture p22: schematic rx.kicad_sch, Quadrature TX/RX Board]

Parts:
C1: 2.2u; C_0805_2012Metric_Pad1.18x1.45mm_HandSolder
C2, C19, C20: 0.1u; C_0805_2012Metric_Pad1.18x1.45mm_HandSolder
C3, C4, C5, C6: 33nF; C_0805_2012Metric_Pad1.18x1.45mm_HandSolder
C13, C14, C15, C16: 4.7n; C_0805_2012Metric_Pad1.18x1.45mm_HandSolder
C17, C18: 10n; C_0805_2012Metric_Pad1.18x1.45mm_HandSolder
R1, R2: 10k; R_0805_2012Metric_Pad1.20x1.40mm_HandSolder
R11, R12: 100; R_0805_2012Metric_Pad1.20x1.40mm_HandSolder
R13, R14, R15, R16: 470; R_0805_2012Metric_Pad1.20x1.40mm_HandSolder
R17, R18, R19, R20: 47; R_0805_2012Metric_Pad1.20x1.40mm_HandSolder
TP1, TP2: TestPoint; TestPoint_Pad_1.5x1.5mm
TR1: Trifilar FT37-43; FT37-43 Trifilar
U1: SN74CBT3253; SOIC-16_3.9x9.9mm_P1.27mm
U2, U3: LM4562; SOIC-8_3.9x4.9mm_P1.27mm

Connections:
+5V: C2.1, C19.1, C20.1, R1.1, U1.16 (VCC), U2.8 (V+), U3.8 (V+); also elsewhere on the board
CLK_I: U1.14 (S0); also elsewhere on the board
CLK_Q: U1.2 (S1); also elsewhere on the board
GND: C1.2, C2.2, C3.2, C4.2, C5.2, C6.2, C19.2, C20.2, R2.2, TR1.4, U1.1 (1~OE), U1.8 (GND), U1.15 (2~OE), U2.4 (V-), U3.4 (V-); also elsewhere on the board
I_MINUS_OUT: C17.1, R14.2, R18.2; also elsewhere on the board
I_PLUS_OUT: C17.2, R13.2, R17.2; also elsewhere on the board
unnamed: C1.1, R1.2, R2.1, TR1.6, TR1.7
unnamed: C13.2, R17.1, U2.1
unnamed: C14.2, R18.1, U2.7
unnamed: C15.2, R19.1, U3.1
unnamed: C16.2, R20.1, U3.7
unnamed: TP2.1, TR1.5, U1.7 (1A)
unnamed: C6.1, U1.6 (1B1), U1.13 (2B4), U2.3 (+)
unnamed: C5.1, U1.5 (1B2), U1.12 (2B3), U3.3 (+)
unnamed: C4.1, U1.4 (1B3), U1.11 (2B2), U3.5 (+)
unnamed: C3.1, U1.3 (1B4), U1.10 (2B1), U2.5 (+)
unnamed: TP1.1, TR1.8, U1.9 (2A)
unnamed: C13.1, R11.1, R13.1, U2.2 (-)
unnamed: C14.1, R11.2, R14.1, U2.6 (-)
unnamed: C15.1, R12.1, R15.1, U3.2 (-)
unnamed: C16.1, R12.2, R16.1, U3.6 (-)
Q_MINUS_OUT: C18.1, R16.2, R20.2; also elsewhere on the board
Q_PLUS_OUT: C18.2, R15.2, R19.2; also elsewhere on the board
RF_IN: TR1.1; also elsewhere on the board

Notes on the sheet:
SOIC-8
SOIC-16

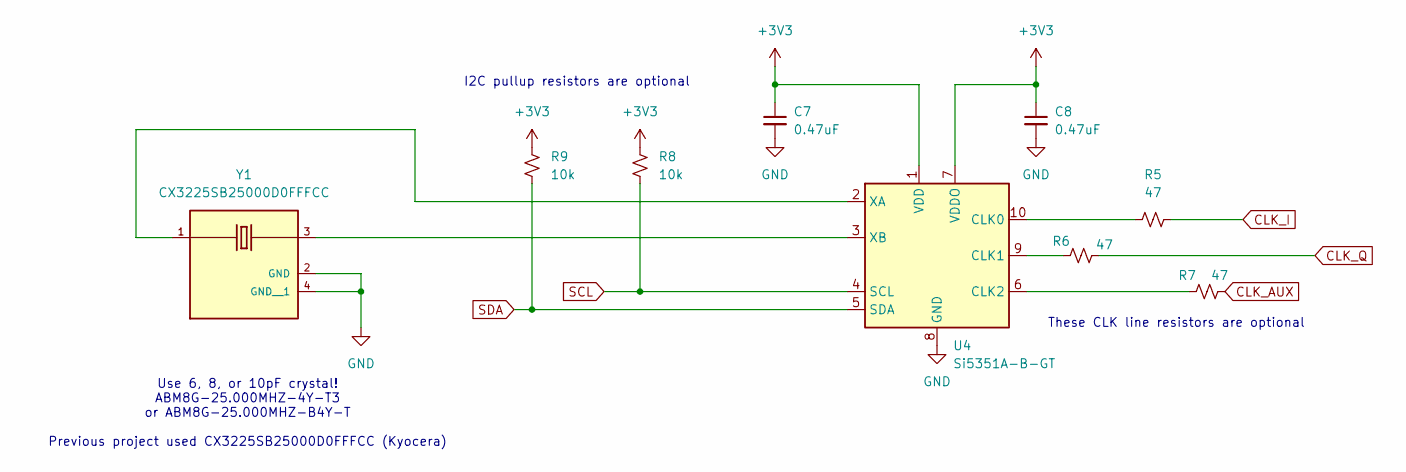
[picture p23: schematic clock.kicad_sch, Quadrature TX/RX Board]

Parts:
C7, C8: 0.47uF; C_0805_2012Metric_Pad1.18x1.45mm_HandSolder
R5, R6, R7: 47; R_0805_2012Metric_Pad1.20x1.40mm_HandSolder
R8, R9: 10k; R_0805_2012Metric_Pad1.20x1.40mm_HandSolder
U4: Si5351A-B-GT; MSOP-10_3x3mm_P0.5mm
Y1: CX3225SB25000D0FFFCC; OSCCC320X250X60N; PARTREV N/A

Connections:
+3V3: C7.1, C8.1, R8.1, R9.1, U4.1 (VDD), U4.7 (VDDO); also elsewhere on the board
CLK_AUX: R7.2; also elsewhere on the board
CLK_I: R5.2; also elsewhere on the board
CLK_Q: R6.2; also elsewhere on the board
GND: C7.2, C8.2, U4.8 (GND), Y1.2 (GND), Y1.4 (GND__1); also elsewhere on the board
unnamed: R5.1, U4.10 (CLK0)
unnamed: R6.1, U4.9 (CLK1)
unnamed: R7.1, U4.6 (CLK2)
unnamed: U4.2 (XA), Y1.1
unnamed: U4.3 (XB), Y1.3
SCL: R8.2, U4.4 (SCL); also elsewhere on the board
SDA: R9.2, U4.5 (SDA); also elsewhere on the board

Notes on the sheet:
These CLK line resistors are optional
I2C pullup resistors are optional
Use 6, 8, or 10pF crystal! ABM8G-25.000MHZ-4Y-T3 or ABM8G-25.000MHZ-B4Y-T Previous project used CX3225SB25000D0FFFCC (Kyocera)

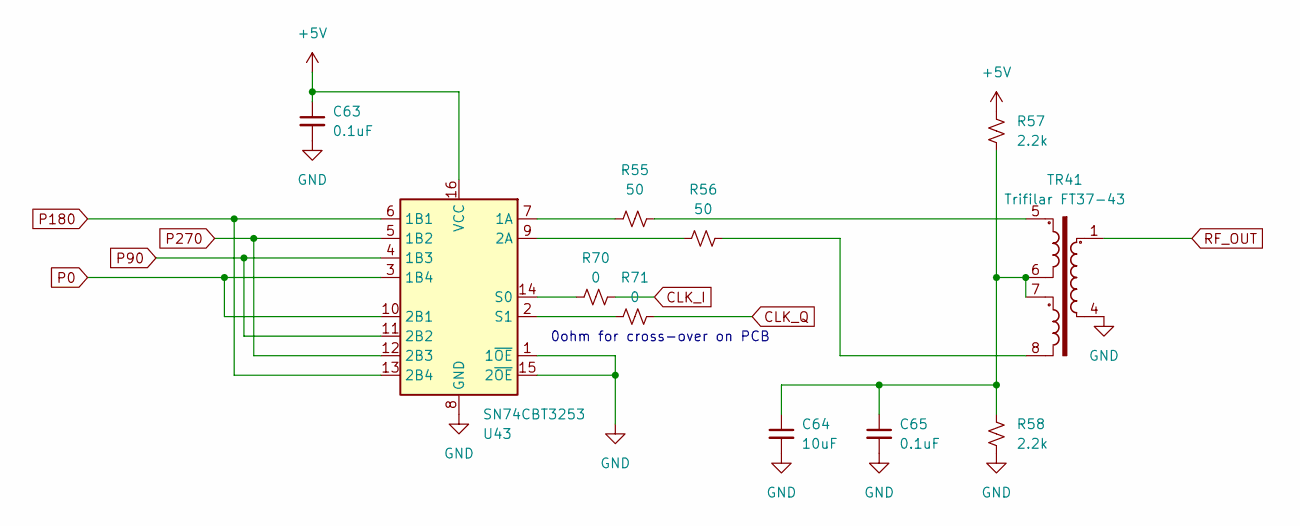
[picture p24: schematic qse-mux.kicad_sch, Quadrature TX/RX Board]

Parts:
C63, C65: 0.1uF; C_0805_2012Metric_Pad1.18x1.45mm_HandSolder
C64: 10uF; C_0805_2012Metric_Pad1.18x1.45mm_HandSolder
R55, R56: 50; R_0805_2012Metric_Pad1.20x1.40mm_HandSolder
R57, R58: 2.2k; R_0805_2012Metric_Pad1.20x1.40mm_HandSolder
R70, R71: 0; R_0805_2012Metric_Pad1.20x1.40mm_HandSolder
TR41: Trifilar FT37-43; FT37-43 Trifilar
U43: SN74CBT3253; SOIC-16_3.9x9.9mm_P1.27mm

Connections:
+5V: C63.1, R57.1, U43.16 (VCC); also elsewhere on the board
CLK_I: R70.2; also elsewhere on the board
CLK_Q: R71.2; also elsewhere on the board
GND: C63.2, C64.2, C65.2, R58.2, TR41.4, U43.1 (1~OE), U43.8 (GND), U43.15 (2~OE); also elsewhere on the board
unnamed: C64.1, C65.1, R57.2, R58.1, TR41.6, TR41.7
unnamed: R55.2, TR41.5
unnamed: R56.2, TR41.8
unnamed: R55.1, U43.7 (1A)
unnamed: R56.1, U43.9 (2A)
unnamed: R70.1, U43.14 (S0)
unnamed: R71.1, U43.2 (S1)
P0: U43.3 (1B4), U43.10 (2B1); also elsewhere on the board
P90: U43.4 (1B3), U43.11 (2B2); also elsewhere on the board
P180: U43.6 (1B1), U43.13 (2B4); also elsewhere on the board
P270: U43.5 (1B2), U43.12 (2B3); also elsewhere on the board
RF_OUT: TR41.1; also elsewhere on the board

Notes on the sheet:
0ohm for cross-over on PCB

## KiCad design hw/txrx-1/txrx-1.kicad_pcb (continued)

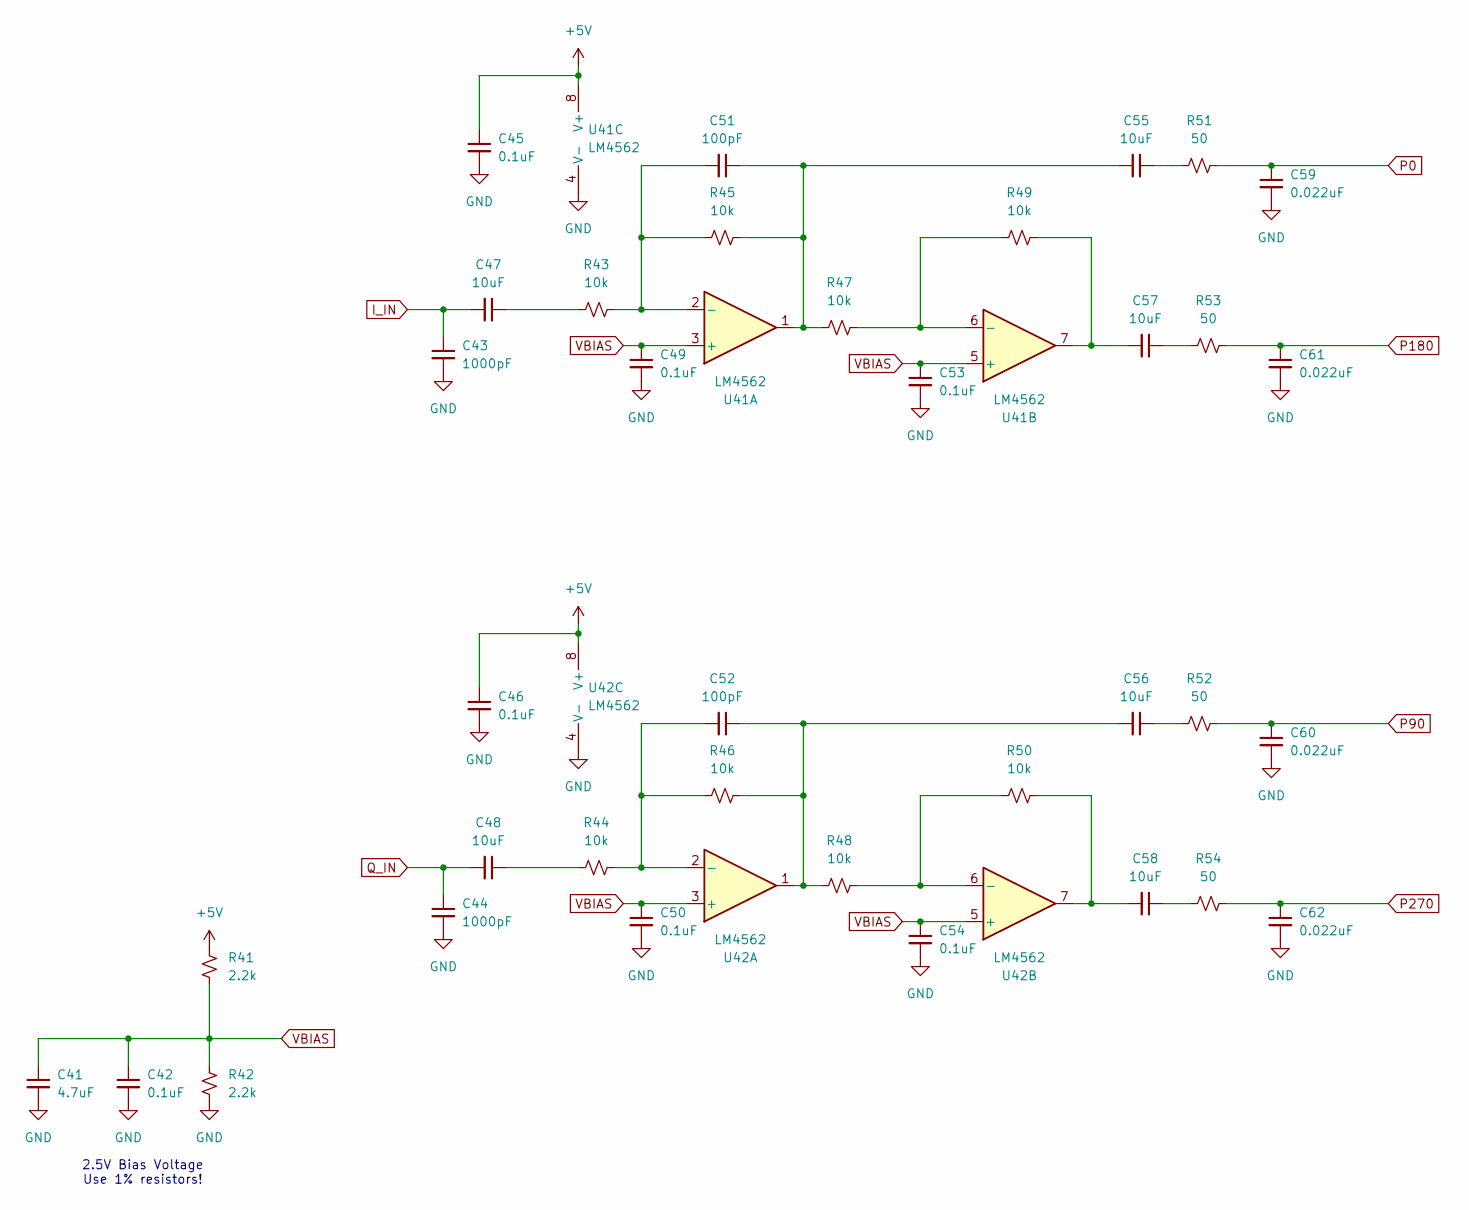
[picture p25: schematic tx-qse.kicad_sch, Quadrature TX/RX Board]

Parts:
C41: 4.7uF; C_0805_2012Metric_Pad1.18x1.45mm_HandSolder
C42, C45, C46, C49, C50, C53, C54: 0.1uF; C_0805_2012Metric_Pad1.18x1.45mm_HandSolder
C43, C44: 1000pF; C_0805_2012Metric_Pad1.18x1.45mm_HandSolder
C47, C48, C55, C56, C57, C58: 10uF; C_0805_2012Metric_Pad1.18x1.45mm_HandSolder
C51, C52: 100pF; C_0805_2012Metric_Pad1.18x1.45mm_HandSolder
C59, C60, C61, C62: 0.022uF; C_0805_2012Metric_Pad1.18x1.45mm_HandSolder
R41, R42: 2.2k; R_0805_2012Metric_Pad1.20x1.40mm_HandSolder
R43, R44, R45, R46, R47, R48, R49, R50: 10k; R_0805_2012Metric_Pad1.20x1.40mm_HandSolder
R51, R52, R53, R54: 50; R_0805_2012Metric_Pad1.20x1.40mm_HandSolder
U41, U42: LM4562; SOIC-8_3.9x4.9mm_P1.27mm

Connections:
+5V: C45.1, C46.1, R41.1, U41.8 (V+), U42.8 (V+); also elsewhere on the board
GND: C41.2, C42.2, C43.2, C44.2, C45.2, C46.2, C49.2, C50.2, C53.2, C54.2, C59.2, C60.2, C61.2, C62.2, R42.2, U41.4 (V-), U42.4 (V-); also elsewhere on the board
I_IN: C43.1, C47.2; also elsewhere on the board
unnamed: C47.1, R43.1
unnamed: C48.1, R44.1
unnamed: C51.1, C55.2, R45.2, R47.1, U41.1
unnamed: C52.1, C56.2, R46.2, R48.1, U42.1
unnamed: C55.1, R51.1
unnamed: C56.1, R52.1
unnamed: C57.1, R53.1
unnamed: C57.2, R49.2, U41.7
unnamed: C58.1, R54.1
unnamed: C58.2, R50.2, U42.7
unnamed: C51.2, R43.2, R45.1, U41.2 (-)
unnamed: R47.2, R49.1, U41.6 (-)
unnamed: C52.2, R44.2, R46.1, U42.2 (-)
unnamed: R48.2, R50.1, U42.6 (-)
P0: C59.1, R51.2; also elsewhere on the board
P90: C60.1, R52.2; also elsewhere on the board
P180: C61.1, R53.2; also elsewhere on the board
P270: C62.1, R54.2; also elsewhere on the board
Q_IN: C44.1, C48.2; also elsewhere on the board
VBIAS: C41.1, C42.1, C49.1, C50.1, C53.1, C54.1, R41.2, R42.1, U41.3 (+), U41.5 (+), U42.3 (+), U42.5 (+)

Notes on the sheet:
2.5V Bias Voltage Use 1% resistors!


Board: 4 copper layers, 70.0 x 100.0 mm, 98 parts (0 on the bottom side), 62 nets.

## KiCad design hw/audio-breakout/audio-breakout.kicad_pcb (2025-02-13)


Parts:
H1, H2, H3, H4: MountingHole; MountingHole_3.5mm
J1: Conn_01x03; PinSocket_1x03_P2.54mm_Vertical
J2: Conn_01x04; PinSocket_1x04_P2.54mm_Vertical
J3: Conn_01x05; PinSocket_1x05_P2.54mm_Vertical
J4, J5: Conn_01x04; PinHeader_1x04_P2.54mm_Vertical
J6: Conn_01x02
JP5, JP6, JP7: SolderJumper_2_Open; SolderJumper-2_P1.3mm_Open_Pad1.0x1.5mm

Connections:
+3.3V: J1.2; also elsewhere on the board
+5V: J1.1; also elsewhere on the board
ADC_BCK: J3.2, JP6.2 (B); also elsewhere on the board
ADC_DOUT: J3.1; also elsewhere on the board
ADC_LRCK: J3.3, JP5.2 (B); also elsewhere on the board
ADC_SCK: J3.4, JP7.2 (B); also elsewhere on the board
DAC_BCK: J2.3, JP6.1 (A); also elsewhere on the board
DAC_DIN: J2.2; also elsewhere on the board
DAC_LRCK: J2.1, JP5.1 (A); also elsewhere on the board
DAC_SCK: J2.4, JP7.1 (A); also elsewhere on the board
INL_MINUS: J4.2; also elsewhere on the board
INL_PLUS: J4.1; also elsewhere on the board
INR_MINUS: J4.3; also elsewhere on the board
INR_PLUS: J4.4; also elsewhere on the board
OUTL: J5.1; also elsewhere on the board
OUTR: J5.3; also elsewhere on the board
~RST: J3.5; also elsewhere on the board

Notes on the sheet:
Optional feature to allow the I2S clock lines for the ADC and DAC to be connected. This could reduce MPU pin count when common clocks are possible.
Control for ADC high-pass filter bypass. Low=normal (i.e. not bypassed), High=bypassed. This is useful for enabling DC calibration of the ADC.


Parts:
C10, C13, C16, C18: 10u; CP_Radial_D4.0mm_P2.00mm
C11, C14, C17, C19: 0.1u; C_0805_2012Metric_Pad1.18x1.45mm_HandSolder
C12, C15: 1u; C_0805_2012Metric_Pad1.18x1.45mm_HandSolder
JP8, JP9, JP10, JP11, JP12, JP13: SolderJumper_3_Bridged12; SolderJumper-3_P1.3mm_Bridged12_Pad1.0x1.5mm
L1: 47u; L_0805_2012Metric_Pad1.15x1.40mm_HandSolder
U2: PCM1804DBR; SSOP-28_5.3x10.2mm_P0.65mm

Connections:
+3.3V: C13.1, C14.1, JP8.1 (A), JP9.3 (B), JP10.1 (A), JP11.3 (B), JP12.3 (B), JP13.1 (A), U2.14 (VDD); also elsewhere on the board
+5V: L1.1; also elsewhere on the board
ADC_BCK: U2.16 (BCK/DSDL); also elsewhere on the board
ADC_DOUT: U2.15 (DATA/DSDR); also elsewhere on the board
ADC_LRCK: U2.17 (LRCK/DSDBCK); also elsewhere on the board
ADC_SCK: U2.18 (SCKI); also elsewhere on the board
FMT0: JP8.2 (C), U2.6 (FMT0)
FMT1: JP9.2 (C), U2.7 (FMT1)
INL_MINUS: U2.5 (VINL-); also elsewhere on the board
INL_PLUS: U2.4 (VINL+); also elsewhere on the board
INR_MINUS: U2.24 (VINR-); also elsewhere on the board
INR_PLUS: U2.25 (VINR+); also elsewhere on the board
unnamed: C18.1, C19.1, L1.2, U2.22 (VCC)
unnamed: C16.1, C17.1, U2.28 (VREFR)
OSR0: JP11.2 (C), U2.9 (OSR0)
OSR1: JP13.2 (C), U2.10 (OSR1)
OSR2: JP12.2 (C), U2.11 (OSR2)
S/~M: JP10.2 (C), U2.8 (S/M)
VCOML: C12.1, U2.3 (VCOML)
VCOMR: C15.1, U2.26 (VCOMR)
VREFL: C10.1, C11.1, U2.1 (VREFL)
~RST: U2.19 (*REST); also elsewhere on the board

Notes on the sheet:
FMT=I2S by default
Slave by default
OSR=010, 384*fs by default
28-SSOP 5.3mm width


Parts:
C1, C2, C4, C7: 0.1uF; C_0805_2012Metric_Pad1.18x1.45mm_HandSolder
C3, C5: 2.2uF; C_0805_2012Metric_Pad1.18x1.45mm_HandSolder
C6: 10uF; CP_Radial_D4.0mm_P2.00mm
C8, C9: 2.2nF; C_0805_2012Metric_Pad1.18x1.45mm_HandSolder
JP1, JP2, JP3, JP4: SolderJumper_3_Bridged12; SolderJumper-3_P1.3mm_Bridged12_Pad1.0x1.5mm
R1, R2: 470; R_0805_2012Metric_Pad1.20x1.40mm_HandSolder
U1: PCM5100; TSSOP-20_4.4x6.5mm_P0.65mm

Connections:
+3.3V: C1.1, C2.1, C4.1, C6.1, JP1.3 (B), JP2.1 (A), JP3.3 (B), JP4.3 (B), U1.1 (CPVDD), U1.8 (AVDD), U1.20 (DVDD); also elsewhere on the board
DAC_BCK: U1.13 (BCK); also elsewhere on the board
DAC_DIN: U1.14 (DIN); also elsewhere on the board
DAC_LRCK: U1.15 (LRCK); also elsewhere on the board
DAC_SCK: U1.12 (SCK); also elsewhere on the board
DEMP: JP3.2 (C), U1.10 (DEMP)
FLT: JP1.2 (C), U1.11 (FLT)
FMT: JP4.2 (C), U1.16 (FMT)
unnamed: C3.2, U1.4 (CAPM)
unnamed: C3.1, U1.2 (CAPP)
unnamed: C7.1, U1.18 (LDOO)
unnamed: R2.2, U1.6 (OUTL)
unnamed: R1.2, U1.7 (OUTR)
unnamed: C5.1, U1.5 (VNEG)
OUTL: C9.1, R2.1; also elsewhere on the board
OUTR: C8.1, R1.1; also elsewhere on the board
XSMT: JP2.2 (C), U1.17 (XSMT)

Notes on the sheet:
FLT Low=Normal Latency
For CPVDD
For DVDD
DEMP Low=De-emphasis off
XSMT High=Soft Unmute
For AVDD
FMT Low=I2S Format

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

Board: 2 copper layers, 76.2 x 41.5 mm, 46 parts (0 on the bottom side), 39 nets.

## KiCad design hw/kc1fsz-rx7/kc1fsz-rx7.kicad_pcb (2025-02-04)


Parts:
C1, C4, C6, C8: 0.1u; C_0805_2012Metric_Pad1.18x1.45mm_HandSolder
C2, C3, C5, C7: 10u; CP_Radial_D4.0mm_P2.00mm
C9, C10: 1u; C_0805_2012Metric_Pad1.18x1.45mm_HandSolder
H1, H2: MountingHole; MountingHole_3mm
J1: IQ; PinHeader_1x06_P2.54mm_Vertical
J2: Power; PinHeader_1x03_P2.54mm_Vertical
J3: Config; PinHeader_1x06_P2.54mm_Vertical
J4: Conn_01x06; PinHeader_1x06_P2.54mm_Vertical
L1: 47u; L_0805_2012Metric_Pad1.15x1.40mm_HandSolder
U1: PCM1804DBR; SSOP-28_5.3x10.2mm_P0.65mm

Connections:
+3.3V: C5.1, C6.1, J2.2, U1.14 (VDD)
+5V: J2.1, L1.1
BCK: J4.4, U1.16 (BCK/DSDL)
DATA: J4.5, U1.15 (DATA/DSDR)
FMT0: J3.1, U1.6 (FMT0)
FMT1: J3.2, U1.7 (FMT1)
GND: C1.2, C2.2, C3.2, C4.2, C5.2, C6.2, C7.2, C8.2, C9.2, C10.2, J2.3, J4.6, U1.2 (AGNDL), U1.12 (BYPAS), U1.13 (DGND), U1.23 (AGND), U1.27 (AGNDR)
I_MINUS: J1.3, U1.5 (VINL-)
I_PLUS: J1.2, U1.4 (VINL+)
LRCK: J4.3, U1.17 (LRCK/DSDBCK)
unnamed: C7.1, C8.1, L1.2, U1.22 (VCC)
unnamed: C3.1, C4.1, U1.28 (VREFR)
OSR0: J3.4, U1.9 (OSR0)
OSR1: J3.5, U1.10 (OSR1)
OSR2: J3.6, U1.11 (OSR2)
Q_MINUS: J1.4, U1.24 (VINR-)
Q_PLUS: J1.5, U1.25 (VINR+)
SCK: J4.2, U1.18 (SCKI)
S/~M: J3.3, U1.8 (S/M)
VCOML: C9.1, J1.1, U1.3 (VCOML)
VCOMR: C10.1, J1.6, U1.26 (VCOMR)
VREFL: C1.1, C2.1, U1.1 (VREFL)
~RST: J4.1, U1.19 (*REST)

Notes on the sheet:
28-SSOP 5.3mm width


Board: 2 copper layers, 34.8 x 29.0 mm, 18 parts (0 on the bottom side), 23 nets.

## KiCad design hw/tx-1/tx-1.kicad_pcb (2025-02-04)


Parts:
H1, H2, H3, H4: MountingHole; MountingHole_3.5mm
J1, J3: Conn_01x04; PinHeader_1x04_P2.54mm_Vertical
J2, J4: Conn_01x02; PinHeader_1x02_P2.54mm_Vertical

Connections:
+5V: J2.1; also elsewhere on the board
CLK_I: J3.1; also elsewhere on the board
CLK_Q: J3.3; also elsewhere on the board
GND: J1.2, J1.4, J2.2, J3.2, J3.4, J4.2; also elsewhere on the board
I_IN: J1.1; also elsewhere on the board
Q_IN: J1.3; also elsewhere on the board
TX_OUT: J4.1; also elsewhere on the board


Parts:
C21, C22: 0.1uF; C_0805_2012Metric_Pad1.18x1.45mm_HandSolder
C23: 4.7uF; C_0805_2012Metric_Pad1.18x1.45mm_HandSolder
R13: 2.2k; R_0805_2012Metric_Pad1.20x1.40mm_HandSolder
R14: 3.3k; R_0805_2012Metric_Pad1.20x1.40mm_HandSolder
R15, R16: 50; R_0805_2012Metric_Pad1.20x1.40mm_HandSolder
TR1: Trifilar FT37-43; FT37-43 Trifilar
U3: SN74CBT3253; SOIC-16_3.9x9.9mm_P1.27mm

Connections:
+5V: C21.1, R14.1, U3.16 (VCC); also elsewhere on the board
CLK_I: U3.14 (S0); also elsewhere on the board
CLK_Q: U3.2 (S1); also elsewhere on the board
GND: C21.2, C22.2, C23.2, R13.2, TR1.4, U3.1 (1~OE), U3.8 (GND), U3.15 (2~OE); also elsewhere on the board
unnamed: C22.1, C23.1, R13.1, R14.2, TR1.6, TR1.7
unnamed: R15.2, TR1.5
unnamed: R16.2, TR1.8
unnamed: R15.1, U3.7 (1A)
unnamed: R16.1, U3.9 (2A)
P0: U3.3 (1B4), U3.10 (2B1); also elsewhere on the board
P90: U3.4 (1B3), U3.11 (2B2); also elsewhere on the board
P180: U3.6 (1B1), U3.13 (2B4); also elsewhere on the board
P270: U3.5 (1B2), U3.12 (2B3); also elsewhere on the board
TX_OUT: TR1.1; also elsewhere on the board


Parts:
C1, C6, C9, C13, C17, C18: 10uF; C_0805_2012Metric_Pad1.18x1.45mm_HandSolder
C2, C11: 1000pF; C_0805_2012Metric_Pad1.18x1.45mm_HandSolder
C3, C5, C8, C12, C14, C16, C25: 0.1uF; C_0805_2012Metric_Pad1.18x1.45mm_HandSolder
C4, C15: 100pF; C_0805_2012Metric_Pad1.18x1.45mm_HandSolder
C7, C10, C19, C20: 0.022uF; C_0805_2012Metric_Pad1.18x1.45mm_HandSolder
C24: 4.7uF; C_0805_2012Metric_Pad1.18x1.45mm_HandSolder
R1, R2, R3, R4, R7, R8, R9, R10: 10k; R_0805_2012Metric_Pad1.20x1.40mm_HandSolder
R5, R6, R11, R12: 50; R_0805_2012Metric_Pad1.20x1.40mm_HandSolder
R17, R18: 2.2k; R_0805_2012Metric_Pad1.20x1.40mm_HandSolder
U1, U2: LM4562; SOIC-8_3.9x4.9mm_P1.27mm

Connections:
+5V: C8.1, C12.1, R17.1, U1.8 (V+), U2.8 (V+); also elsewhere on the board
GND: C2.2, C3.2, C5.2, C7.2, C8.2, C10.2, C11.2, C12.2, C14.2, C16.2, C19.2, C20.2, C24.2, C25.2, R18.2, U1.4 (V-), U2.4 (V-); also elsewhere on the board
I_IN: C1.2, C2.1; also elsewhere on the board
unnamed: C1.1, R1.1
unnamed: C4.1, C9.2, R2.2, R3.1, U1.1
unnamed: C6.1, R5.1
unnamed: C6.2, R4.2, U1.7
unnamed: C9.1, R6.1
unnamed: C13.1, R7.1
unnamed: C15.1, C17.2, R8.2, R9.1, U2.1
unnamed: C17.1, R11.1
unnamed: C18.1, R12.1
unnamed: C18.2, R10.2, U2.7
unnamed: C4.2, R1.2, R2.1, U1.2 (-)
unnamed: R3.2, R4.1, U1.6 (-)
unnamed: C15.2, R7.2, R8.1, U2.2 (-)
unnamed: R9.2, R10.1, U2.6 (-)
P0: C10.1, R6.2; also elsewhere on the board
P90: C19.1, R11.2; also elsewhere on the board
P180: C7.1, R5.2; also elsewhere on the board
P270: C20.1, R12.2; also elsewhere on the board
Q_IN: C11.1, C13.2; also elsewhere on the board
VBIAS: C3.1, C5.1, C14.1, C16.1, C24.1, C25.1, R17.2, R18.1, U1.3 (+), U1.5 (+), U2.3 (+), U2.5 (+)

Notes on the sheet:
2.5V Bias Voltage

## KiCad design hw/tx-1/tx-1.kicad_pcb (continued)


Board: 2 copper layers, 68.0 x 41.0 mm, 55 parts (0 on the bottom side), 31 nets.

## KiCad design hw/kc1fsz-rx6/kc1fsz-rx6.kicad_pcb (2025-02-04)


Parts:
C1, C3, C4, C5: 33nF; C_0805_2012Metric_Pad1.18x1.45mm_HandSolder
C2: 2.2u; C_0805_2012Metric_Pad1.18x1.45mm_HandSolder
C6, C7, C15, C16: 4.7n; C_0805_2012Metric_Pad1.18x1.45mm_HandSolder
C8, C9, C12, C13, C18, C19, C20: 0.1u; C_0805_2012Metric_Pad1.18x1.45mm_HandSolder
C10, C14: 10u; C_0805_2012Metric_Pad1.18x1.45mm_HandSolder
C11, C17: 10n; C_0805_2012Metric_Pad1.18x1.45mm_HandSolder
H1, H2, H3, H4: MountingHole; MountingHole_3.5mm
J1: Conn_Coaxial; SMA_Amphenol_901-144_Vertical
J2: Conn_01x07; PinHeader_1x07_P2.54mm_Vertical
J3: Power; PinHeader_1x02_P2.54mm_Vertical
J4: Clock; PinHeader_1x04_P2.54mm_Vertical
R1, R2: 10k; R_0805_2012Metric_Pad1.20x1.40mm_HandSolder
R3, R14: 100; R_0805_2012Metric_Pad1.20x1.40mm_HandSolder
R4, R5, R15, R16: 470; R_0805_2012Metric_Pad1.20x1.40mm_HandSolder
R6, R7, R12, R13: 470k; R_0805_2012Metric_Pad1.20x1.40mm_HandSolder
R8, R11: 100k; R_0805_2012Metric_Pad1.20x1.40mm_HandSolder
R9, R10, R17, R18, R19, R20: 47; R_0805_2012Metric_Pad1.20x1.40mm_HandSolder
TP1, TP2: TestPoint; TestPoint_Pad_1.5x1.5mm
TR1: Trifilar FT37-43; FT37-43 Trifilar
U1: SN74CBT3253; SOIC-16_3.9x9.9mm_P1.27mm
U2, U3: LM4562; SOIC-8_3.9x4.9mm_P1.27mm

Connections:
+5V: C18.1, C19.1, C20.1, J3.1, R1.1, U1.16 (VCC), U2.8 (V+), U3.8 (V+)
CLK_I: R19.1, U1.14 (S0)
CLK_Q: R20.1, U1.2 (S1)
GND: C1.2, C2.2, C3.2, C4.2, C5.2, C10.1, C14.1, C18.2, C19.2, C20.2, J1.2 (Ext), J2.7, J3.2, J4.2, J4.4, R2.2, TR1.4, U1.1 (1~OE), U1.8 (GND), U1.15 (2~OE), U2.4 (V-), U3.4 (V-)
I_MINUS: C11.1, J2.2, R5.2, R10.2
I_PLUS: C11.2, J2.1, R4.2, R9.2
unnamed: C2.1, R1.2, R2.1, TR1.6, TR1.7
unnamed: C6.2, R9.1, U2.1
unnamed: C7.2, R10.1, U2.7
unnamed: C10.2, R6.2, R7.1, R8.2
unnamed: C14.2, R11.2, R12.2, R13.1
unnamed: C15.2, R17.1, U3.1
unnamed: C16.2, R18.1, U3.7
unnamed: J1.1 (In), TR1.1
unnamed: J4.1, R19.2
unnamed: J4.3, R20.2
unnamed: TP1.1, TR1.5, U1.7 (1A)
unnamed: C5.1, C8.1, U1.6 (1B1), U1.13 (2B4)
unnamed: C4.1, C13.1, U1.5 (1B2), U1.12 (2B3)
unnamed: C3.1, C12.1, U1.4 (1B3), U1.11 (2B2)
unnamed: C1.1, C9.1, U1.3 (1B4), U1.10 (2B1)
unnamed: TP2.1, TR1.8, U1.9 (2A)
unnamed: C8.2, R6.1, U2.3 (+)
unnamed: C6.1, R3.1, R4.1, U2.2 (-)
unnamed: C9.2, R7.2, U2.5 (+)
unnamed: C7.1, R3.2, R5.1, U2.6 (-)
unnamed: C13.2, R12.1, U3.3 (+)
unnamed: C15.1, R14.1, R15.1, U3.2 (-)
unnamed: C12.2, R13.2, U3.5 (+)
unnamed: C16.1, R14.2, R16.1, U3.6 (-)
Q_MINUS: C17.1, J2.5, R16.2, R18.2
Q_PLUS: C17.2, J2.4, R15.2, R17.2
VCOML: J2.3, R8.1
VCOMR: J2.6, R11.1

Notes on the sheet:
SOIC-8
SOIC-16


Board: 2 copper layers, 60.2 x 46.5 mm, 54 parts (0 on the bottom side), 34 nets.

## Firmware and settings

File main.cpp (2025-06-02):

/**
 * Pico I2S Demonstration
 * Copyright (C) 2025, Bruce MacKinnon
 *
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
 * NOT FOR COMMERCIAL USE WITHOUT PERMISSION.
 *  
 */

/*
Command used to load code onto the board: 

~/git/openocd/src/openocd -s ~/git/openocd/tcl -f interface/cmsis-dap.cfg -f target/rp2350.cfg -c "adapter speed 5000" -c "rp2350.dap.core1 cortex_m reset_config sysresetreq" -c "program main.elf verify reset exit"

*/
#include <stdio.h>
#include <math.h>
#include <cstring>

#include <arm_math.h>

#include "pico/stdlib.h"
#include "pico/time.h"
#include "hardware/clocks.h"
#include "hardware/dma.h"
#include "hardware/sync.h"
#include "hardware/i2c.h"

#include "kc1fsz-tools/rp2040/PicoPollTimer.h"
#include "kc1fsz-tools/rp2040/PicoPerfTimer.h"

#include "i2s.pio.h"
#include "si5351.h"
#include "sweeper.h"

#define I2C0_SDA_PIN (16)  // Physical pin 21
#define I2C0_SCL_PIN (17)  // Physical pin 22
#define I2C1_SDA_PIN (2)  
#define I2C1_SCL_PIN (3)  
#define LED_PIN (PICO_DEFAULT_LED_PIN)

using namespace kc1fsz;

// ####################################################################
// TODO: MOVE
struct delay_instance_f32 {
    float* state; 
    unsigned int stateSize;
    unsigned int nextWrite;
};

void delay_init_f32(delay_instance_f32* inst, 
    unsigned int maxDelayTaps, float* state, unsigned int blockSize) {
    inst->state = state;
    inst->stateSize = blockSize + maxDelayTaps;
    inst->nextWrite = 0;
}

void delay_f32(delay_instance_f32* inst, 
    const float* in, float* out, unsigned int blockSize, 
    unsigned int delayTaps) {
    if (blockSize + delayTaps > inst->stateSize)
        assert(false);
    for (unsigned int i = 0; i < blockSize; i++) {
        // Calculate the read location, taking into account
        // wraps around the start of the state.
        unsigned int nextRead;
        if (inst->nextWrite >= delayTaps)
            nextRead = inst->nextWrite - delayTaps;
        else 
            nextRead = inst->stateSize + inst->nextWrite - delayTaps;
        // Get the output
        out[i] = inst->state[nextRead];
        inst->state[inst->nextWrite] = in[i];
        // Advance and manage wrap
        inst->nextWrite++;
        if (inst->nextWrite == inst->stateSize)
            inst->nextWrite = 0;
    }
}
// ####################################################################

//#define ADC_SAMPLE_COUNT (512)
//#define ADC_SAMPLE_BYTES_LOG2 (12)
//#define DAC_SAMPLE_BYTES_LOG2 (12)

#define ADC_SAMPLE_COUNT (256)
#define ADC_SAMPLE_BYTES_LOG2 (11)
#define DAC_SAMPLE_BYTES_LOG2 (11)

// Buffer used to drive the DAC via DMA.
// 2* for L and R
#define DAC_BUFFER_SIZE (ADC_SAMPLE_COUNT * 2)
// 4* for 32-bit integers
#define DAC_BUFFER_ALIGN (DAC_BUFFER_SIZE * 4)
// 4096-byte alignment is needed because we are using a DMA channel in ring mode
// and all buffers must be aligned to a power of two boundary.
// 256 samples * 2  words per sample * 4 bytes per word = 2048 bytes
static __attribute__((aligned(DAC_BUFFER_ALIGN))) uint32_t dac_buffer_ping[DAC_BUFFER_SIZE];
static __attribute__((aligned(DAC_BUFFER_ALIGN))) uint32_t dac_buffer_pong[DAC_BUFFER_SIZE];

// Buffer used to drive the ADC via DMA.
// When running at 48kHz, each buffer of 384 samples represents 8ms of activity
// When running at 48kHz, each buffer of 512 samples represents 10ms of activity
// The *2 accounts for left + right channels
#define ADC_BUFFER_SIZE (ADC_SAMPLE_COUNT * 2)
// Here is where the actual audio data gets written
// The *2 accounts for the fact that we are double-buffering.
static __attribute__((aligned(8))) uint32_t adc_buffer[ADC_BUFFER_SIZE * 2];
// Here is where the buffer addresses are stored to control ADC DMA
// The *2 accounts for the fact that we are double-buffering.
static __attribute__((aligned(8))) uint32_t* adc_addr_buffer[2];

// Diagnostic counters
static volatile uint32_t dma_in_count = 0;
static volatile uint32_t dma_out_count = 0;
static volatile uint32_t proc_count = 0;
static volatile uint32_t max_proc_0 = 0;

static uint dma_ch_in_ctrl = 0;
static uint dma_ch_in_data = 0;
static uint dma_ch_out_data0 = 0;
static uint dma_ch_out_data1 = 0;

// Enabled inside ADC DMA IRQ to indicate that a new frame is available
static volatile bool adc_frame_ready = false;
// This flag is used to manage the alternating buffers. "ping open"
// indicates that the ping buffer was just written and should be sent
// out on the next opportunity. Otherwise, it's the pong buffer that
// was just written and is waiting to be sent.
static volatile bool dac_buffer_ping_open = false;

static PicoPerfTimer timer_0;

/*
#define HILBERT_IMPULSE_SIZE (51)
static const float hilbert_impulse[HILBERT_IMPULSE_SIZE] = {
0.012442742396853695, -9.247429900666847e-16, 0.009007745694645828, 3.886440143014065e-16, 0.012248270003437301, 2.0291951727332382e-16, 0.016267702606548327, 1.073881019267362e-15, 0.021262591317853616, -1.5445700787658912e-15, 0.027540135461651433, 9.040409971208902e-16, 0.03555144114893796, -9.736771998276128e-17, 0.04616069183085064, 2.5884635757740463e-16, 0.060879120316970736, -1.9452769758181735e-16, 0.08310832605502039, 6.688463706336815e-16, 0.12163479949392442, -4.100082211906412e-17, 0.208751841831881, 3.007875123018464e-16, 0.635463817659196, 0, -0.635463817659196, -3.007875123018464e-16, -0.208751841831881, 4.100082211906412e-17, -0.12163479949392442, -6.688463706336815e-16, -0.08310832605502039, 1.9452769758181735e-16, -0.060879120316970736, -2.5884635757740463e-16, -0.04616069183085064, 9.736771998276128e-17, -0.03555144114893796, -9.040409971208902e-16, -0.027540135461651433, 1.5445700787658912e-15, -0.021262591317853616, -1.073881019267362e-15, -0.016267702606548327, -2.0291951727332382e-16, -0.012248270003437301, -3.886440143014065e-16, -0.009007745694645828, 9.247429900666847e-16, -0.012442742396853695
};
*/

#define HILBERT_IMPULSE_SIZE (71)
static float hilbert_impulse[HILBERT_IMPULSE_SIZE] = {
0.003280158972196459, -2.6913320235605067e-07, 0.00281406062078617, -9.161363096266983e-07, 0.003985021414434486, -1.618587666932063e-06, 0.005450999350074075, -1.9189040647516074e-06, 0.007262664727861606, -2.360314424730244e-06, 0.00948053959593801, -2.1703343573990264e-06, 0.012181883403014827, -2.5628817403290866e-06, 0.015461200723989862, -7.066359931599645e-07, 0.019459515188764917, -3.2918847746577675e-06, 0.024362576948291248, -3.386452949263455e-06, 0.030473764476294157, -3.5184352949003947e-06, 0.0382687121226955, -4.391933037083758e-06, 0.04857005331189018, -3.953559009023066e-06, 0.06294804140744603, -2.314572775720779e-06, 0.08477848616922334, -1.6697579050910363e-06, 0.12285835532250555, -1.5223564667124609e-06, 0.2095022309647281, -1.9124822250834506e-06, 0.6357140091664184, 0, -0.6357140091664184, 1.9124822250834506e-06, -0.2095022309647281, 1.5223564667124609e-06, -0.12285835532250555, 1.6697579050910363e-06, -0.08477848616922334, 2.314572775720779e-06, -0.06294804140744603, 3.953559009023066e-06, -0.04857005331189018, 4.391933037083758e-06, -0.0382687121226955, 3.5184352949003947e-06, -0.030473764476294157, 3.386452949263455e-06, -0.024362576948291248, 3.2918847746577675e-06, -0.019459515188764917, 7.066359931599645e-07, -0.015461200723989862, 2.5628817403290866e-06, -0.012181883403014827, 2.1703343573990264e-06, -0.00948053959593801, 2.360314424730244e-06, -0.007262664727861606, 1.9189040647516074e-06, -0.005450999350074075, 1.618587666932063e-06, -0.003985021414434486, 9.161363096266983e-07, -0.00281406062078617, 2.6913320235605067e-07, -0.003280158972196459
};

// Build the group-delay in samples.
// This is assuming an odd Hilbert size.
// NOTE: The +2 seems to give slightly better rejection
//#define HILBERT_GROUP_DELAY ((HILBERT_IMPULSE_SIZE + 1) / 2) + 2
// USE THIS VERSION WITH phaseCal:
#define HILBERT_GROUP_DELAY ((HILBERT_IMPULSE_SIZE + 1) / 2)

/*
#define LPF_IMPULSE_SIZE (51)
static float lpf_impulse[LPF_IMPULSE_SIZE] = {
-0.007988518488193047, -0.0322923540338797, -0.0025580477346377516, -0.007508482037031126, -0.0015547763074605164, 0.003280642290253403, 0.008795348444624476, 0.013112016273176279, 0.015229588003704697, 0.014260356689224188, 0.009841832366608681, 0.002295390261866158, -0.007296945242233224, -0.01717660135976687, -0.025298778719890665, -0.029398991822789773, -0.027623603206855935, -0.018731596787559205, -0.0025587380614820365, 0.020105815714798622, 0.04727569765636943, 0.07608694879779716, 0.10336445155058628, 0.12570901987001032, 0.14037248973886046, 0.14550041816800013, 0.14037248973886046, 0.12570901987001032, 0.10336445155058628, 0.07608694879779716, 0.04727569765636943, 0.020105815714798622, -0.0025587380614820365, -0.018731596787559205, -0.027623603206855935, -0.029398991822789773, -0.025298778719890665, -0.01717660135976687, -0.007296945242233224, 0.002295390261866158, 0.009841832366608681, 0.014260356689224188, 0.015229588003704697, 0.013112016273176279, 0.008795348444624476, 0.003280642290253403, -0.0015547763074605164, -0.007508482037031126, -0.0025580477346377516, -0.0322923540338797, -0.007988518488193047
};
*/

#define LPF_IMPULSE_SIZE (91)
static float lpf_impulse[LPF_IMPULSE_SIZE] = {
0.026023731209180712, -0.014944709238861435, -0.01282048293469228, -0.011606039275329378, -0.010593560098382651, -0.00924125050458392, -0.007286060750618341, -0.004648438806810258, -0.0015355909555464862, 0.00171013338400933, 0.0045964325270102255, 0.006672390629168848, 0.007523840203798958, 0.006943597991965513, 0.004907442913820445, 0.0017317488367759044, -0.002112573413878447, -0.005956312807227829, -0.00905892246527812, -0.010785308726788935, -0.010650672953206002, -0.008495597575241154, -0.004513733345988606, 0.0007693820564916878, 0.006489959083732819, 0.011662090756684888, 0.01522931867508315, 0.01634570240113426, 0.014472103355133298, 0.009568210608822089, 0.0020876523550769467, -0.006951746454653754, -0.01615006622499047, -0.023815670331730376, -0.028272268352863006, -0.02806697519845502, -0.02215747488201716, -0.010297917934256877, 0.007255778779401038, 0.029207770582472974, 0.05373554159034625, 0.0786499018999863, 0.10140628513007802, 0.1196538139172792, 0.13142332055479838, 0.13550049513969512, 0.13142332055479838, 0.1196538139172792, 0.10140628513007802, 0.0786499018999863, 0.05373554159034625, 0.029207770582472974, 0.007255778779401038, -0.010297917934256877, -0.02215747488201716, -0.02806697519845502, -0.028272268352863006, -0.023815670331730376, -0.01615006622499047, -0.006951746454653754, 0.0020876523550769467, 0.009568210608822089, 0.014472103355133298, 0.01634570240113426, 0.01522931867508315, 0.011662090756684888, 0.006489959083732819, 0.0007693820564916878, -0.004513733345988606, -0.008495597575241154, -0.010650672953206002, -0.010785308726788935, -0.00905892246527812, -0.005956312807227829, -0.002112573413878447, 0.0017317488367759044, 0.004907442913820445, 0.006943597991965513, 0.007523840203798958, 0.006672390629168848, 0.0045964325270102255, 0.00171013338400933, -0.0015355909555464862, -0.004648438806810258, -0.007286060750618341, -0.00924125050458392, -0.010593560098382651, -0.011606039275329378, -0.01282048293469228, -0.014944709238861435, 0.026023731209180712
};

// State buffers/etc for FIR filters
static float hilbert_delay_state[HILBERT_IMPULSE_SIZE + ADC_SAMPLE_COUNT - 1];
static float hilbert_fir_state[HILBERT_IMPULSE_SIZE + ADC_SAMPLE_COUNT - 1];
static float lpf_fir_state[LPF_IMPULSE_SIZE + ADC_SAMPLE_COUNT - 1];
static arm_fir_instance_f32 hilbert_fir;
static arm_fir_instance_f32 lpf_fir;
static arm_cfft_instance_f32 audio_fft;
static delay_instance_f32 hilbert_delay;

static float tx_lpf_fir_state[LPF_IMPULSE_SIZE + ADC_SAMPLE_COUNT - 1];
static float tx_hilbert_delay_state[HILBERT_IMPULSE_SIZE + ADC_SAMPLE_COUNT - 1];
static float tx_hilbert_fir_state[HILBERT_IMPULSE_SIZE + ADC_SAMPLE_COUNT - 1];
static arm_fir_instance_f32 tx_lpf_fir;
static arm_fir_instance_f32 tx_hilbert_fir;
static delay_instance_f32 tx_hilbert_delay;

// ----- Adjustable Parameters ----------------------------------

static int32_t freq = 7255000;
// Calibration
//static int32_t cal = 490;
static int32_t cal = 750;
// LSB/USB selector
static bool modeLSB = true;
static bool modeTX = false;

// Scale when producing audio output
static float rxDacScale = 80.0;
// Used to trim I/Q imbalance on input
static float rxImbalanceScale = 0.97;
static int rxPhaseCal = -2;

// Scale when producing I/Q output
static float txDacScale = 1.0;
static float txImbalanceScale = 0.98;
static int txPhaseCal = 0;

// ----- Sweeper Integration ------------------------------------------

/*
class SweeperContextImpl : public SweeperContext {
public:

    void setFreq(unsigned int freqHz) {
        si_evaluate(0, freqHz + cal);
    }

    unsigned int getRMS() const {
        float total = 0;
        for (unsigned int i = 0; i < AN_BUFFER_SIZE; i++) {
            total += pow(lpf_buffer[i], 2.0);
        }
        return sqrt(total);
    }
};
*/

static void process_in_frame_rx();
static void process_in_frame_tx();
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
int main(int argc, const char** argv) {

    // Get all of the ARM CMSIS-DSP structures setup
    arm_fir_init_f32(&hilbert_fir, 
        HILBERT_IMPULSE_SIZE, hilbert_impulse, hilbert_fir_state, ADC_SAMPLE_COUNT);
    arm_fir_init_f32(&lpf_fir, 
        LPF_IMPULSE_SIZE, lpf_impulse, lpf_fir_state, ADC_SAMPLE_COUNT);
    //arm_cfft_init_512_f32(&audio_fft);
    arm_cfft_init_256_f32(&audio_fft);
    // NEW
    delay_init_f32(&hilbert_delay, HILBERT_IMPULSE_SIZE - 1, hilbert_delay_state, ADC_SAMPLE_COUNT);

    arm_fir_init_f32(&tx_hilbert_fir, 
        HILBERT_IMPULSE_SIZE, hilbert_impulse, tx_hilbert_fir_state, ADC_SAMPLE_COUNT);
    arm_fir_init_f32(&tx_lpf_fir, 
        LPF_IMPULSE_SIZE, lpf_impulse, tx_lpf_fir_state, ADC_SAMPLE_COUNT);
    // NEW
    delay_init_f32(&tx_hilbert_delay, HILBERT_IMPULSE_SIZE - 1, tx_hilbert_delay_state, ADC_SAMPLE_COUNT);

    unsigned long fs = 48000;

    // Pin to be allocated to I2S SCK (output to CODEC)
    // GP10 is physical pin 14
    uint sck_pin = 4;
    // ADC pins
    // Pin to be allocated to ~RST
    uint rst_pin = 5;
    // Pin to be allocated to I2S DIN (input from)
    uint din_pin = 6;
    // DAC pins
    // Pin to be allocated to I2S DOUT 
    uint dout_pin = 9;

    unsigned long system_clock_khz = 129600;

    // Adjust system clock to more evenly divide the 
    // audio sampling frequency.
    set_sys_clock_khz(system_clock_khz, true);

    stdio_init_all();

    gpio_init(LED_PIN);
    gpio_set_dir(LED_PIN, GPIO_OUT);

    // Audio out shutdown
    gpio_init(12);
    gpio_set_dir(12, GPIO_OUT);
    gpio_put(12, 0);

    gpio_init(rst_pin);
    gpio_set_dir(rst_pin, GPIO_OUT);
    gpio_put(rst_pin, 1);

    // Startup ID
    sleep_ms(500);
    sleep_ms(500);

    printf("Minimal SDR2\nCopyright (C) Bruce MacKinnon KC1FSZ, 2025\n");
    printf("Freq %d\n", freq);

    //generateTestTone();

    // ===== Si5351 Initialization =============================================

    // I2C bus setup
    i2c_init(i2c0, 100 * 1000);
    gpio_set_function(I2C0_SDA_PIN, GPIO_FUNC_I2C);
    gpio_set_function(I2C0_SCL_PIN, GPIO_FUNC_I2C);
    gpio_pull_up(I2C0_SDA_PIN);
    gpio_pull_up(I2C0_SCL_PIN);
    i2c_set_baudrate(i2c0, 100000);

    // I2C SCAN
    printf("\nI2C Bus Scan\n");
    printf("   0  1  2  3  4  5  6  7  8  9  A  B  C  D  E  F\n");
    
    for (int addr = 0; addr < (1 << 7); ++addr) {
      if (addr % 16 == 0) {
        printf("%02x ", addr);
      }

      int ret;
      uint8_t rxdata;
      ret = i2c_read_blocking(i2c0, addr, &rxdata, 1, false);

      printf(ret < 0 ? "." : "@");
      printf(addr % 16 == 15 ? "\n" : "  ");
    }

    init_si5351();
    // Change freq
    si_evaluate(0, freq + cal);
    printf("Si5351 initialized 3\n");

    // ===== PCM1804 A/D Converter Setup ======================================

    // TODO: REVIEW WHETHER THIS IS NEEDED
    // Reset the CODEC
    gpio_put(rst_pin, 0);
    sleep_ms(100);
    gpio_put(rst_pin, 1);
    sleep_ms(100);

    // ===== PCM5100 DAC Setup ===============================================

    // ===== I2S SCK PIO Setup ===============================================

    // Allocate state machine
    uint sck_sm = pio_claim_unused_sm(pio0, true);
    uint sck_sm_mask = 1 << sck_sm;

    // Load PIO program into the PIO
    uint sck_program_offset = pio_add_program(pio0, &i2s_sck_program);
  
    // Setup the function select for a GPIO to use output from the given PIO 
    // instance.
    // 
    // PIO appears as an alternate function in the GPIO muxing, just like an 
    // SPI or UART. This function configures that multiplexing to connect a 
    // given PIO instance to a GPIO. Note that this is not necessary for a 
    // state machine to be able to read the input value from a GPIO, but only 
    // for it to set the output value or output enable.
    pio_gpio_init(pio0, sck_pin);

    // NOTE: The xxx_get_default_config() function is generated by the PIO
    // assembler and defined inside of the generated .h file.
    pio_sm_config sck_sm_config = 
        i2s_sck_program_get_default_config(sck_program_offset);
    // Associate pin with state machine. 
    // Because we are using the "SET" command in the PIO program
    // (and not OUT or side-set) we use the set_set function here.
    sm_config_set_set_pins(&sck_sm_config, sck_pin, 1);
    // Initialize setting and direction of the pin before SM is enabled
    uint sck_pin_mask = 1 << sck_pin;
    pio_sm_set_pins_with_mask(pio0, sck_sm, 0, sck_pin_mask);
    pio_sm_set_pindirs_with_mask(pio0, sck_sm, sck_pin_mask, sck_pin_mask);
    // Hook it all together.  (But this does not enable the SM!)
    pio_sm_init(pio0, sck_sm, sck_program_offset, &sck_sm_config);

    // Adjust state-machine clock divisor.  Remember that we need
    // the state machine to run at 2x SCK speed since it takes two 
    // instructions to achieve one clock transition on the pin.
    //
    // NOTE: The clock divisor is in 16:8 format
    //
    // d d d d d d d d d d d d d d d d . f f f f f f f f
    //            Integer Part         |  Fraction Part
    unsigned int sck_sm_clock_d = 3;
    unsigned int sck_sm_clock_f = 132;
    // Sanity check:
    // 2 * (3 + (132/256)) = 7.03125
    // 7.03125 * 48,000 * 384 = 129,600,000
    pio_sm_set_clkdiv_int_frac(pio0, sck_sm, sck_sm_clock_d, sck_sm_clock_f);

    // Final enable of the SCK state machine
    pio_enable_sm_mask_in_sync(pio0, sck_sm_mask);

    // Now issue a reset of the CODEC
    // Per datasheet page 18: "Because the system clock is used as a clock signal
    // for the reset circuit, the system clock must be supplied as soon as the 
    // power is supplied ..."
    //
    sleep_ms(100);
    gpio_put(rst_pin, 0);
    sleep_ms(5);
    gpio_put(rst_pin, 1);

    // Per PCM1804 datasheet page 18: 
    //
    // "The digital output is valid after the reset state is released and the 
    // time of 1116/fs has passed."
    // 
    // Assuming fs = 40,690 hz, then we must wait at least 27ms after reset!

    sleep_ms(50);

    // ===== I2S LRCK, BCK, DIN Setup (ADC) =====================================

    // Allocate state machine
    uint din_sm = pio_claim_unused_sm(pio0, true);
    uint din_sm_mask = 1 << din_sm;
    
    // Load master ADC program into the PIO
    uint din_program_offset = pio_add_program(pio0, &i2s_din_master_program);
  
    // Setup the function select for a GPIO to use from the given PIO 
    // instance.
    // DIN
    pio_gpio_init(pio0, din_pin);
    gpio_set_pulls(din_pin, false, false);
    gpio_set_dir(din_pin, GPIO_IN);
    // BCK
    pio_gpio_init(pio0, din_pin + 1);
    gpio_set_dir(din_pin + 1, GPIO_OUT);
    // LRCK
    pio_gpio_init(pio0, din_pin + 2);
    gpio_set_dir(din_pin + 2, GPIO_OUT);

    // NOTE: The xxx_get_default_config() function is generated by the PIO
    // assembler and defined inside of the generated .h file.
    pio_sm_config din_sm_config = 
        i2s_din_master_program_get_default_config(din_program_offset);
    // Associate the input pin with state machine.  This will be 
    // relevant to the DIN pin for IN instructions.
    sm_config_set_in_pins(&din_sm_config, din_pin);
    // Set the "side set pins" for the state machine. 
    // These are BCLK and LRCLK
    sm_config_set_sideset_pins(&din_sm_config, din_pin + 1);
    // Configure the IN shift behavior.,,,,,
    // Parameter 0: "false" means shift ISR to left on input.
    // Parameter 1: "true" means autopush is enabled.
    // Parameter 2: "32" means threshold (in bits) before auto/conditional 
    //              push to the ISR.
    sm_config_set_in_shift(&din_sm_config, false, true, 32);
    // Merge the FIFOs since we are only doing RX.  This gives us 
    // 8 words of buffer instead of the usual 4.
    sm_config_set_fifo_join(&din_sm_config, PIO_FIFO_JOIN_RX);

    // Initialize the direction of the pins before SM is enabled
    // There are three pins in the mask here. 
    uint din_pins_mask = 0b111 << din_pin;
    // DIN: The "0" means input, "1" means output
    uint din_pindirs   = 0b110 << din_pin;
    pio_sm_set_pindirs_with_mask(pio0, din_sm, din_pindirs, din_pins_mask);
    // Start with the two clocks in 1 state.
    uint din_pinvals   = 0b110 << din_pin;
    pio_sm_set_pins_with_mask(pio0, din_sm, din_pinvals, din_pins_mask);
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

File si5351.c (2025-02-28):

/*
 * si5351.c
 *
 * Created: Jan 2020
 * Author: Arjan
 *
 * Driver for the SI5351A VCO
 *
 
Si5351 principle of operation:
==============================
Crystal frequency Fxtal (usually 25MHz) is multiplied in a PLL by MSN to obtain Fvco.
PLLs A and B have independent MSN values, leading to two Fvco frequencies.
The output Fout on each channel (i) can be derived from either Fvco.
Fvco must be between 600MHz and 900MHz, but the spec is more relaxed in reality.
In the second stage, an Fvco is divided by MSi and Ri to obtain the output frequency Fout.
Only certain values of MSi and Ri are allowed when quadrature output is required.

Tuning stragtegy:
MSi and Ri are selected to be in the ballpark of desired frequency range.
MSN is then used for tuning Fout.

Details:
========

             +-------+             +-------+     +------+
   Fxtal --> | * MSN | -- Fvco --> | / MSi | --> | / Ri | -- Fout -->
             +-------+             +-------+     +------+

 MSN determines:          Fvco = Fxtal * (MSN)      , where MSN = a + b/c
 MSi and Ri determine:    Fout = Fvco / (Ri*MSi)    , where MSi = a + b/c	(note: different a, b and c)
 
 
 ---Derivation of the register values, that determine MSN and MSi---
 P1 = 128*a + Floor(128*b/c) - 512		(P1 = calculated for MSN tuning,  P1 = 750MHz/Fout for MSi integer mode)
 P2 = 128*b - c*Floor(128*b/c)			(P2 = calculated for MSN tuning,  P2 = 0 for MSi integer mode)
 P3 = c									(P3 = c = 1000000 for MSN tuning, P3 = 1 for MSi integer mode)
 
 
 This VFO implementation assigns PLLA to VFO 0 (clk0 and clk1), and PLLB to VFO 1 (clk2)
 
 The algorithm to get from required Fout to synthesizer settings:
 | calculate new <MSN> from the desired <Fout>, based on the current <Ri> and <MSi>
 | if MSN is still inside [600/Fxtal, 900/Fxtal]
 | then
 |   just update the MSN related registers
 | else 
 |   re-calculate <MSi>, <Ri> and <MSN> from desired <Fout>
 |   write the <MSi> and <Ri> parameter registers, including phase offset (MSi equals phase offset for 90 deg, use INV to shift 180deg more)
 |   write the <MSN> parameter registers
 |   reset PLL
 (this all assumes that the current settings are consistent, i.e. must be initialized at startup)

Calculate MSi:
	MSi = 750MHz/(Fout*Ri)	// Target for mid-band, i.e. Fvco=750MHz
	MSi &= 0xfe				// Make it even, minimum is 4 in case of integer mode

Calculate MSN:
	MSN = MSi*Ri*Fout/Fxtal (spec mandates between 24 and 36, but could be stretched)
	
	
Some boundary values, assuming 600M < Fvco < 900M.
With low end 400M, Low MHz is multiplied with 2/3.
------------+--------------+-----------------------+
Ri		MSi	:	a	b	c  |    Low MHz	  High MHz
1		  4	:	4	0	1  | 150.000000	225.000000	
1		126	: 126	0	1  |   4.761905	  7.142857
32		  4	:	4	0	1  |   4.687500	  7.031250
32		126	:  126	0	1  |   0.148810	  0.223214
128		  4	:	4	0	1  |   1.171875	  1.757813
128		126	:  126	0	1  |   0.037202	  0.055804

NOTE: Phase offsets
The PHOFF is given as a multiple of 1/(4*Fvco), so when MSi == PHOFF the shift will be 90deg.
It also implies that MSi must be an integer, and Ri == 1.

Only use MSi even-integers, i.e. a=[4, 6, 8..126], b=0 and c=100000, and set INT bits in reg 22, 23. 
Quadrature Phase offsets (i.e. delay): 
- Phase offset for MS0 (reg 165) must be 0 (cos: delay = 0), 
- Phase offset for MS1 (reg 166) must be equal to divider MS1 for 90 deg (sin: delay = MSi / 4*Fvco),
- Set INV bit (reg 17) to add 180 deg.

This implies that minimum Fout is 4.762MHz at Fvco = 600MHz. 
Additional flip/flop dividers are needed to get down to 80m band frequencies, or Fvco must be tuned below spec.

 
Control Si5351 (see AN619):
===========================
----+---------+---------+---------+---------+---------+---------+---------+---------+
 @	|    7    |    6    |    5    |    4    |    3    |    2    |    1    |    0    |
----+---------+---------+---------+---------+---------+---------+---------+---------+
  0	|SYS_INIT |  LOL_B  |  LOL_A  |   LOS   |      Reserved     |      REVID[1:0]   |
  1	|SYS_INIT |  LOS_B  |  LOL_A  |   LOS   |                Reserved               |
	|    _STKY|    _STKY|    _STKY|    _STKY|                Reserved               |
  2	|SYS_INIT |  LOS_B  |  LOL_A  |   LOS   |                Reserved               |
	|    _MASK|    _MASK|    _MASK|    _MASK|                Reserved               |
  3	|                   Reserved                      | CLK2_EN | CLK1_EN | CLK0_EN |
====
  9	|                   Reserved                      |OEB_MASK2|OEB_MASK1|OEB_MASK0|
====
 15 |  CLKIN_DIV[2:0]   |    0    |    0    | PLLB_SRC| PLLA_SRC|    0    |    0    |
 16 | CLK0_PDN| MS0_INT | MS0_SRC | CLK0_INV|   CLK0_SRC[1:0]   |   CLK0_IDRV[1:0]  |
 17 | CLK1_PDN| MS1_INT | MS1_SRC | CLK1_INV|   CLK1_SRC[1:0]   |   CLK1_IDRV[1:0]  |
 18 | CLK2_PDN| MS2_INT | MS2_SRC | CLK2_INV|   CLK2_SRC[1:0]   |   CLK2_IDRV[1:0]  |
====
 22 | Reserved| FBA_INT |                          Reserved                         |
 23 | Reserved| FBB_INT |                          Reserved                         |
 24 |      Reserved     |   CLK2_DIS_STATE  |   CLK1_DIS_STATE  |   CLK0_DIS_STATE  |
====
 26 |                                  MSNA_P3[15:8]                                |
 27 |                                  MSNA_P3[7:0]                                 |
 28	|                         Reserved                          |   MSNA_P1[17:16]  |
 29 |                                  MSNA_P1[15:8]                                |
 30 |                                  MSNA_P1[7:0]                                 |
 31 |             MSNA_P3[19:16]            |             MSNA_P2[19:16]            |
 32 |                                  MSNA_P2[15:8]                                |
 33 |                                  MSNA_P2[7:0]                                 |
 
 34: Same pattern for PLLB

 42 |                                  MS0_P3[15:8]                                 |
 43 |                                  MS0_P3[7:0]                                  |
 44 | Reserved|      R0_DIV[2:0]            |  MS0_DIVBY4[1:0]  |   MS0_P1[17:16]   |
 45 |                                  MS0_P1[15:8]                                 |
 46 |                                  MS0_P1[7:0]                                  |
 47 |              MS0_P3[19:16]            |              MS0_P2[19:16]            |
 48 |                                  MS0_P2[15:8]                                 |
 49 |                                  MS0_P2[7:0]                                  |

 50: Same pattern for CLK1
 
 58: Same pattern for CLK2
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

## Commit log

2025-01-26 Moving in hardware projects
    [kc1fsz-rx6.kicad_pcb, kc1fsz-rx6.kicad_sch, kc1fsz-rx7.kicad_pcb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]
2025-01-27 Ready to send audio breakout to fab
    [adc.kicad_sch, audio-breakout.kicad_pcb, audio-breakout.kicad_sch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]
2025-01-28 TX board
    [qse-mux.kicad_sch, qse.kicad_sch, tx-1.kicad_pcb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]
2025-01-28 Working on TX
    [qse-mux.kicad_sch, qse.kicad_sch, tx-1.kicad_sch]
2025-01-29 Layout of TX board complete
    [tx-1.kicad_pcb]
2025-01-29 Ready to sent to fab
    [tx-1.kicad_pcb]
2025-02-05 Slave mode problem resoled, now having a timing issue
    [main.cpp]
2025-02-09 DAC working with DMA finally!
2025-02-10 Switched over to SMSIS DSP functions - not tested yet.
2025-02-11 Getting very close to working. Still a problem with pure tones
    [main.cpp]
2025-02-13 New board for power, etc
    [audio-out.kicad_sch, power.kicad_sch, util-1.kicad_pcb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]
2025-02-13 Initial version of PCB layout
    [audio-in.kicad_sch, audio-out.kicad_sch, power.kicad_sch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]
2025-02-14 Added changes to mic preamp ground plane
    [util-1.kicad_pcb]
2025-02-14 Sending to OSHPark
    [util-1.kicad_pcb]
2025-02-16 Working on converged TX/RX board
    [clock.kicad_sch, qse-mux.kicad_sch, rx.kicad_sch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]
2025-02-17 Initial PCB layout for TXRX board
    [clock.kicad_sch, qse-mux.kicad_sch, rx.kicad_sch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]
2025-02-17 Final version being sent to fab
    [clock.kicad_sch, qse-mux.kicad_sch, rx.kicad_sch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]
2025-02-18 Sending revision of util-1 to JLCPCB
    [audio-in.kicad_sch, clock.kicad_sch, util-1.kicad_pcb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]
2025-02-24 First commit of BPF-1
    [bpf-1.kicad_pcb, bpf-1.kicad_sch]
2025-02-24 Ready to send to fab
    [bpf-1.kicad_pcb]
2025-02-28 Working on new boards
2025-03-02 Refacting with new board

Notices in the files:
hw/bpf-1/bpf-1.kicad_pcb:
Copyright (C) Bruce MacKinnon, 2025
